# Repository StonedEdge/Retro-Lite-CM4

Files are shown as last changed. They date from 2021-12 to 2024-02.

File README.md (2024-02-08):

Image of Retro Lite CM4
# Retro Lite CM4: Raspberry Pi Handheld

## Description
 
The Retro Lite CM4 is a joint project between Dmcke5 and StonedEdge. The console is powered by a 4000mAh Li-Po and is designed to run with various software images, including but not limited to RetroPie, Lakka or Batocera, directly from an SD card or via eMMC storage. The project housing was inspired by a Nintendo Switch Lite, but is not a 100% match to the original. The CM4 cannot currently emulate most 32/64-bit consoles released after the PSP or Dreamcast. This means GameCube, Wii and 3DS are currently unplayable until the Foundation releases a newer version of the Compute Module line. wiringPi is now a deprecated GPIO library however does work with arm64 and aarch64, so you can install 64-bit RetroPie if you'd like. 

## Features

- Machined aluminum 6061 housing (green/purple), custom machined and anodized by Dmcke5
- Raspberry Pi 4 SoC: Broadcom BCM2711 quad-core Cortex-A72 @ 1.5GHz (ARM CPU overclockable to 2.1GHz, GPU overclockable to 850MHz)
- 2GB of LPDDR4-3200 SDRAM
- 5.0GHz IEEE 802.11b/g/n/ac wireless, Bluetooth 5.0
- Custom AIO 4-layer PCB, with CM4 mezzanines, 5v boost rated at 2.1A continuous current, 3.3v buck, USB2422 hub, BQ24292i, MAX17055 fuel gauge, ATtiny84, WM8960 amp, TFP401 encoder, SD card slot, USB-C hardware and mini HDMI type A
- 2x controller PCBs with FFC cables
- 800 x 480 (5:3 aspect ratio) IPS display
- HDMI video output (HDMI0 - internal)
- 1080p 60fps HDMI video output (HDMI1 - external) via the mini HDMI port
- Tempered glass screen protector
- Fuel gauge for accurate battery SoC monitoring - MAX17055, custom battery indicator shown in steps of 10 icons, plus %SoC value, via dispmanx APIs on a TFT HDMI driven panel
- Charging indicator
- HDMI switching scripts, to shutdown and reboot to external HDMI with an overclock applied
- ATMEGA32u4 internal USB 2.0 HID controller
- Brightness and volume HUD adjustment, in steps of 10 icons. Brightness is adjusted by holding select + up/down on the DPAD
- Custom menu, activated by pushing select + R3. The menu consists of 4 sections (1. Battery Information, 2. Controller Calibration, 3. Onscreen Keyboard, 4. Settings Menu) -   courtesy of Dmcke5's hard work and ideas :D
- USB-C PD charging capabilities up to 15v (0.5C charge rate at 2A) with an original Nintendo Switch charger
- Stereo Audio Output via i2s WM8960 Wolfson audio amplifier
- Headphone jack, with automatic switching
- 4000mAh custom lipo design, providing 4 hours of gameplay
- Dual stacked shoulder buttons (L, R, LZ, RZ)
- 2x switch analog sticks, range programmable in software
- Resin casted ABXY, DPAD, start+select, shoulder buttons with acetal spring hinge + silicone membranes
- Safe software/hardware shutdown to prevent corruption to the SD card data (low voltage shutdown included)
- USB 2.0 2-port downstream hub
- External dock passthrough PCB with 4 port USB-hub - have now started uploading dock assets

Click the link below to view a more detailed buildlog of the Retro Lite CM4: 
https://bitbuilt.net/forums/index.php?threads/retro-lite-cm4-a-stonededge-and-dmcke5-collaboration.3934/

## Requirements to Build the Retro Lite CM4

### Code 

Code has now been split into various header files and the retrolite.c code has now been made easier to read and condensed for the end-user. Code required to complete the handheld includes an ATtiny84 monitor script, which can be flashed via the 1.27mm pitch 6 pin header on the main Retro Lite PCB with an Arduino or similar programmer. Code for the i2s audio amplifier, fuel gauge and OSD functionality can be compiled directly on the CM4 module from the command line. Current code is unfinished as of January 2022, however we are pushing bug fixes when we find them - expect a fully functioning RetroPie image to be shared in the future from this repository (actually, just found out this is not allowed due to the licensing of certain emulators, so will create install scripts at a later date). 

To flash the software to the Retro Lite CM4, you can either download the latest RetroPie Retro Lite custom image, or follow the below steps to get up and running. Plan is to eventually put this into a single script. I have not currently tested our firmware on images other than RetroPie, however I assume other images should also work fine. 

a) Download the latest version of RetroPie for the Raspberry Pi 4/400 here (also compatible with CM4): 
https://retropie.org.uk/download/ 

b) Run the WM8960 I2S audio amplifier script and install audio drivers:
https://github.com/StonedEdge/seeed-voicecard

c) Install the latest version of WiringPi, compatible with both 64/32-bit OS here: 
https://github.com/StonedEdge/WiringPi

d) Add config.txt to the /boot directory (overwrite)

e) cd /home/pi/RetroliteOSD sudo make - compile the Retro Lite CM4 C code and generate binary

f) Navigate to the /etc directory and add the below lines to the rc.local file, to allow the code to run every time at startup 

cd /home/pi/RetroliteOSD
sudo ./retrolite &
sudo ./hdmi_script.sh & 

g) sudo reboot - Reboot to enable all changes 

You should now have all the required software installed for the Retro Lite CM4 to display battery SoC, charging status, WiFi status, bluetooth status and more. The Retro Lite CM4 automatically safely shuts itself down when the voltage of the batteries depletes to 3.1V - adjustable directly from the settings calibration menu. The Retro Lite CM4 must reboot to output video to an external monitor via the mini HDMI type-A port, which is handled by the hdmi_switch.sh script. 

-------------------------------------------------------------------------------------------------------

### CAD
The CAD files for the Retro Lite CM4 are now available and open source! Please do give credit where due as a lot of work has gone into these designs.
You can check out my project partner's work here: https://github.com/dmcke5

-------------------------------------------------------------------------------------------------------

### PCB
The Retro Lite CM4 requires 4 custom designed PCBs to be installed, not including the CM4 carrier board. These include: 

a) Retro Lite CM4 AIO carrier board 

b) Retro Lite Controller PCB (Right)

c) Retro Lite Controller PCB (Left)

d) Retro Lite Button Daughterboard

Gerbers to be ordered from your board house of choice have now been uploaded! Recommended to use JLCPCB for fast turnaround using their 4-layer service.

-------------------------------------------------------------------------------------------------------

### BOM (Bill of Materials) 
Preliminary BOMs for all 4 PCBs have been added including cost. You will have to source your own parts however most can be found on Digikey/Mouser.

-------------------------------------------------------------------------------------------------------
### New Revision Features
Features that I would like to add to the handheld (welcome for others to assist) include the following:

a) HDMI over USB-C, using the TPS65987D and the TUSB546A-DCI high speed mux. 

b) OTG integration (power perihperals through the onboard USB-C port). 

c) DSI 5.5" display (struggle to know of a way to get this working currently on the Pi). 

Feel free to make a pull request with any changes you would like seen to the handheld. 

-------------------------------------------------------------------------------------------------------

### FAQs
Q: How can I get my hands one of these handhelds? Do you sell them? 

A: I am not currently selling kits on this handheld (nor do I plan to for the forseeable future), but I do offer commissions on occassion via my social media. DM me for details. 

Q: Why dont you use a 5.5" display from a Switch Lite? 

A: MIPI reverse engineering is not simple not trivial to a hobbyist like myself. 

Q: Why are your commissions ludicrously priced?

A: Building one off handhelds for people is expensive. Labor & parts dont come cheap either. I'd recommend you build one yourself using the assets from this GitHub or just buy a mass produced emulation handheld from Aliexpress. 

### Optional Docking Station 
Image of Retro Lite CM4

Source code available here:
https://github.com/StonedEdge/Retro-Lite-CM4-Dock

The docking station is now completed! It's designed to work with RetroPie and use a RP2040 microcontroller, written in C (Pico) and Python (CM4). Feel free to build one if you'd like! 

-------------------------------------------------------------------------------------------------------
### Contributors 
I'd like to thank these people in no particular order for the awesome work you have done to help me complete this project. 

* Dmcke5 for designing the case assets, including machining/anodizing the prototypes, doing most of the code and much more. Wouldn't have been possible to complete this without you - a team effort
* YveltalGriffin/Mackie-Kannard Smith, for suggesting various hardware changes and reviews to PCB/schematics + GitHub bugs. His help was invaluable in learning new things about PCB design 
* Juckett D, for creating the Aegis CM4 and offering tips and tricks along the way. Check out his work here and awesome CM4 handheld(s): https://github.com/juckettd
* Aurelio Manarra, for always helping me out with my non EE questions and various other things ᕕ( ᐛ )ᕗ
* Bill, for helping me with the docking station code & bug fixes

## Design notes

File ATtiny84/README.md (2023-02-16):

# ATtiny84 C++ Script

## Description
The purpose of the ATtiny84 onboard micrcontroller is to perform 5 simple functions: 

1) Drive the EN pin of the boost/buck regulators high, to turn on system power 
2) Safely shutdown the operating system via a push button, and shut off regulator output after a reasonable delay (in this case, 10 seconds)
3) Safely shutdown the operating system when battery voltage depletes less than 3.1v to prevent undervoltage/prolong the battery lifespan. This can be set as low as 2.8v but I would not recommend setting it lower than 3.0v to maintain good battery health 
4) Monitor the BQ24292i charging chip over i2c, including setting the correct parameters/registers for the Retro Lite CM4, like max charge current and voltage cutoffs
5) Allow for specific time delays before performing actions (i.e hold button 3 seconds for power off, 1 second power on. 10 second delay before regulators switched off, 30 second low voltage shutdown delay) - adjustable via the powerOn, powerOff, and shutDown variables
6) Set the CM4 to the lowest possible power down state by driving GLOBAL_EN low after software shutdown

### Install Instructions

The easiest way to flash the ATtiny84 is with an Arduino UNO set up as an ICSP (in-circuit serial programmer) directly from within the Arduino IDE.
https://www.arduino.cc/en/software

Please install the below ATtiny cores for Arduino IDE support and choose the internal 8Mhz clock at 5v when programming your ATtiny84. 
https://github.com/damellis/attiny

For further understanding of the BQ24292i, please check the official datasheet below. Magic number code (i.e directly writing hexadecimal values to the write registers) will be eliminated soon, with proper bitshifting logic to be implemented at a later date. 
https://www.ti.com/lit/ds/symlink/bq24292i.pdf

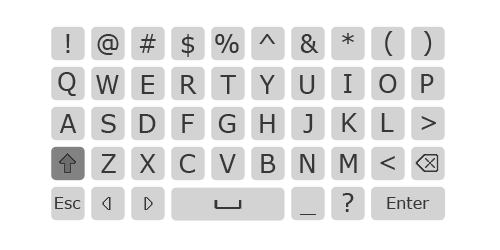
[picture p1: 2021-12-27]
keyboard/upperCase.png

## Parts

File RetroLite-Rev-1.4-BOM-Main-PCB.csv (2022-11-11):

Qty | Available | Value | Device | Package | Board Desginator | Voltage Rating | Power Rating | Description | Additional Notes to PCBA House | Manufacturer Part Number | Unit Price | Total Price | SMT | THT | Original | Remark
1 | YES | N/A | LEDSML0603 | 603 | LEDN_ACT | >3.3V | <1W | Green LED |  | Generic/Cheapest OK | 0.030 | 0.030 | 2 |  | N
1 | YES | N/A | LEDSML0603 | 603 | LEDN_PWR | >3.3V | <1W | Red LED |  | Generic/Cheapest OK | 0.030 | 0.030 | 2 |  | N | New added 20211124
6 | YES | 0 | R-EU_R0402 | 402 | JU_1, JU_2, JU_3, JU_4, JU_5, JU_6 |  | 1/8W or 1/4W | Resistor Jumper |  | Generic/Cheapest OK | 0.000 | 0.000 | 12 |  | N
16 | YES | 0.01uF | CAP_CERAMIC0603_NO | 603 | C2, C3, C5, C6, C7, C8, C9, C10, C11, C21, C22, C25, C49, C51, C53, C54 | >16V | CAP CER SMD 0603 .01UF 10% X7R | Capacitor |  | Generic/Cheapest OK | 0.000 | 0.000 | 32 |  | N
1 | YES | 0.047uF | C-EUC0603 | 603 | C29 | >50V | CAP CER 0.047UF 50V X7R 0603 | Capacitor |  | Generic/Cheapest OK | 0.000 | 0.000 | 2 |  | N
1 | YES | 0.1uF | 0.1UF-0603-25V-(+80/-20%) | 402 | C37 | >10V | CAP CER 1UF 10V X5R 0603 | Capacitor |  | Generic/Cheapest OK | 0.000 | 0.000 | 2 |  | N
1 | YES | 0.1uF | C-EUC0402 | 402 | C65 | >10V | CAP CER 0.1UF 10V X5R 0402 | Capacitor |  | Generic/Cheapest OK | 0.000 | 0.000 | 2 |  | N
7 | ? | 0.1uF | C-EUC0603 | 603 | C12, C13, C17, C18, C19, C26, C62 | >10V | CAP CER 0.1UF 10V X5R 0603 | Capacitor |  | Generic/Cheapest OK | 0.000 | 0.000 | 14 |  | N
1 | ? | 0.1uF | CAP_CERAMIC0603_NO | 603 | C20 | >10V | CAP CER 0.1UF 10V X5R 0603 | Capacitor |  | Generic/Cheapest OK | 0.000 | 0.000 | 2 |  | N
1 | YES | 0.47uF | C-EUC0402 | 402 | C64 | >25V | CAP CER 0.47UF 25V X5R 0402 | Capacitor |  | Generic/Cheapest OK | 0.000 | 0.000 | 2 |  | N
2 | YES | 1-1734839-4 | 1-1734839-4 | TE_1-1734839-4 | LEFTPCB, RIGHTPCB |  |  | Connectors (Controller, Left & Right) |  | Generic/Cheapest OK | 1.081 | 2.162 | 28 |  | Y | Change to original
6 | YES | 1.0uF | 1.0UF-0603-16V-10% | 603 | C41, C42, C43, C44, C47, C68 | >10V | CAP CER 1UF 10V X5R 0603 | Capacitor |  | Generic/Cheapest OK | 0.020 | 0.120 | 12 |  | N
1 | ? | 100k | 100KOHM-0603-1/10W-1% | 402 | R24 |  | 1/10W | Resistor |  | Generic/Cheapest OK | 0.020 | 0.020 | 2 |  | N
1 | YES | 100k | R-EU_R0603 | 603 | R21 |  | 1/8W or 1/4W | Resistor |  | Generic/Cheapest OK | 0.000 | 0.000 | 2 |  | N | 1/10W
1 | YES | 100nF | C-EUC0603 | 603 | C39 | >16V | CAP CER 0.1UF 16V X7R 0603 | Capacitor |  | Generic/Cheapest OK | 0.000 | 0.000 | 2 |  | N
2 | NO | 100uF | C-EUC1206 | 1206 | C35, C36 | >4V | CAP CER 100UF 4V X6S 1206 | Capacitor |  | Generic/Cheapest OK | 0.280 | 0.560 | 4 |  | N
1 | ? | 33k | R-EU_R0603 | 603 | R23 |  | 1/10W | Resistor |  | Generic/Cheapest OK | 0.000 | 0.000 | 2 |  | N
5 | YES | 10 | R-EU_R0603 | 603 | R15, R16, R17, R18, R19 |  | 1/8W or 1/4W | Resistor |  | Generic/Cheapest OK | 0.000 | 0.000 | 10 |  | N | 1/10W
2 | YES | 10k | R-EU_R0402 | 402 | R43, R49 |  | 1/8W or 1/4W | Resistor |  | Generic/Cheapest OK | 0.000 | 0.000 | 4 |  | N | 1/16W
9 | YES | 10k | R-EU_R0603 | 603 | R10, R31, R34, R36, R37, R42, R44, R52, R56 |  | 1/8W or 1/4W | Resistor |  | Generic/Cheapest OK | 0.000 | 0.000 | 18 |  | N | 1/10W
2 | YES | 10k | R-EU_R0603 | 603 | R45, R46 |  | 1/8W or 1/4W | Resistor |  | Generic/Cheapest OK | 0.000 | 0.000 | 4 |  | N | 1/10W
2 | YES | 10uF | 1.0UF-0805-25V-(+80/-20%) | 805 | C46, C59 | >6.3V | CAP CER 10UF 6.3V X5R 0805 | Capacitor |  | Generic/Cheapest OK | 0.020 | 0.040 | 4 |  | N
2 | YES | 10uF | C-EUC0805 | 805 | C66, C67 | >6.3V | CAP CER 10UF 6.3V X5R 0805 | Capacitor |  | Generic/Cheapest OK | 0.020 | 0.040 | 4 |  | N
5 | YES | 10uF | C-EUC0805 | 805 | C4, C23, C27, C28, C31 | >6.3V | CAP CER 10UF 6.3V X5R 0805 | Capacitor |  | Generic/Cheapest OK | 0.020 | 0.100 | 10 |  | N
1 | YES | 1140084168 | 1140084168 | AMPHENOL_1140084168 | M-SD |  | CAP CER 10UF 6.3V X5R 0805 | Connector |  | Generic/Cheapest OK | 0.950 | 0.950 | 14 |  | N
1 | ? | 12k | 12KOHM-0603-1/10W-1% | 603 | R25 |  | 1/10W | Resistor |  | Generic/Cheapest OK | 0.000 | 0.000 | 2 |  | N
1 | YES | 12k | R-EU_R0603 | 603 | R2 |  | 1/8W or 1/4W | Resistor |  | Generic/Cheapest OK | 0.000 | 0.000 | 2 |  | N | 1/10W
1 | YES | 15k | R-EU_R0603 | 603 | R55 |  | 1/8W or 1/4W | Resistor |  | Generic/Cheapest OK | 0.000 | 0.000 | 2 |  | N | 1/10W
1 | YES | 162k | R-US_R0603 | 603 | R35 |  | 1/8W or 1/4W | Resistor |  | Generic/Cheapest OK | 0.000 | 0.000 | 2 |  | N | 1/10W
1 | YES | 18nF | CAP_CERAMIC0603_NO | 603 | C61 | >10V | CAP CER 0.018UF 25V X7R 0603 | Capacitor |  | Generic/Cheapest OK | 0.000 | 0.000 | 2 |  | N
2 | YES | 18pF | C-EUC0603 | 603 | C45, C48 | >10V | CAP CER 18PF 25V 0603 | Capacitor |  | Generic/Cheapest OK | 0.000 | 0.000 | 4 |  | N
1 | ? | 1k | R-US_R0603 | 603 | R30 |  | 1/10W | Resistor |  | Generic/Cheapest OK | 0.000 | 0.000 | 2 |  | N
2 | YES | 1k | R-EU_R0603 | 603 | R13, R54 |  | 1/8W or 1/4W | Resistor |  | Generic/Cheapest OK | 0.000 | 0.000 | 4 |  | N | 1/10W
4 | YES | 1uF | C-EUC0603 | 603 | C30, C38, C40, C55 | >10V | CAP CER 1UF 10V X5R 0603 | Capacitor |  | Generic/Cheapest OK | 0.012 | 0.048 | 8 |  | N
2 | YES | 1uF | C-EUC0805 | 805 | C33, C34 | >25V | CAP CER 1UF 25V X7R 0805 | Capacitor |  | Generic/Cheapest OK | 0.015 | 0.030 | 4 |  | N
3 | YES | 1uF | CAP_CERAMIC0603_NO | 603 | C32, C60, C63 | >10V | CAP CER 1UF 10V X5R 0603 | Capacitor |  | Generic/Cheapest OK | 0.012 | 0.036 | 6 |  | N
2 | YES | 1uF | C-EUC0603 | 603 | C56, C69 | >10V | CAP CER 1UF 10V X5R 0603 | Capacitor |  | Generic/Cheapest OK | 0.012 | 0.024 | 4 |  | N
1 | YES | 1uF | C-EUC0805 | 805 | C1 | >25V | CAP CER 1UF 25V X7R 0805 | Capacitor |  | Generic/Cheapest OK | 0.015 | 0.015 | 2 |  | N
1 | ? | 2.2k | R-EU_R0603 | 603 | R48 |  | 1/10W | Resistor |  | Generic/Cheapest OK | 0.000 | 0.000 | 2 |  | N
1 | YES | 2026560021 | 2026560021 | CONN_2026560021_MOL | J3 |  |  | Fan Connector |  | 2026560021 | 0.620 | 0.620 | 4 |  | Y
1 | YES | 220nF | C-EUC0603 | 603 | C57 | >10V | CAP CER 0603 220NF 16V X7R 10% | Capacitor |  | Generic/Cheapest OK | 0.000 | 0.000 | 2 |  | N
3 | YES | 22uF | CAP_CERAMIC0603_NO | 603 | C24, C50, C52 | >6.3V | CAP CER 22UF 6.3V X5R 0603 | Capacitor |  | Generic/Cheapest OK | 0.100 | 0.300 | 6 |  | N
1 | YES | 22uH | VLCF4020T-220MR56 | VLCF4020_1 | L8 |  | CAP CER 22UF 6.3V X5R 0603 | TDK VLCF4020 Series Shielded Wire-wound SMD Inductor 22 uH +/-20% 800mA |  | VLCF4020T-220MR56 | 0.960 | 0.960 | 2 |  | Y
1 | NO | 24LC02BT-I/OT | EEPROM_I2C_MCP24AA32 | SOT23-5 | U2 |  |  | Microchip 32K (4K x 8) 1.8V I2C EEPROM | https://www.digikey.com/en/products/detail/microchip-technology/24LC02BT-I-LT/2039839 This should work as an alternative… | 24LC02BT-I/OT |  |  |  |  |  | change to DNI 20220528
1 | YES | 261 | R-EU_R0603 | 603 | R41 |  | 1/8W or 1/4W | Resistor |  | Generic/Cheapest OK | 0.000 | 0.000 | 2 |  | N | 1/10W
7 | YES | 33 | CAT16-330J4LFCT-ND | CAT16-330J4LFCT-ND | R1, R6, R7, R8, R9, R12, R14 |  | 1/8W or 1/4W | Resistor | RES ARRAY 4 RES 33 OHM 1206 | Generic/Cheapest OK | 0.020 | 0.140 | 56 |  | N | 1/10W
6 | YES | 4.7k | R-EU_R0603 | 603 | R5, R32, R33, R38, R47, R53 |  | 1/8W or 1/4W | Resistor |  | Generic/Cheapest OK | 0.000 | 0.000 | 12 |  | N | 1/10W
2 | YES | 4.7k | RESISTOR_0603_NOOUT | 603 | R3, R4 |  | 1/8W or 1/4W | Resistor |  | Generic/Cheapest OK | 0.000 | 0.000 | 4 |  | N | 1/10W
3 | YES | 4.7uF | C-EUC0603 | 603 | C14, C15, C16 | >10V | CAP CER 4.7UF 10V X5R 0603 | Capacitor |  | Generic/Cheapest OK | 0.050 | 0.150 | 6 |  | N
1 | ? | 4.7uF 50v | C-EUC0603 | 805 | C58 | >10V | CAP CER 4.7UF 10V X5R 0603 | Capacitor |  | Generic/Cheapest OK | 0.050 | 0.050 | 2 |  | N | 10V
2 | YES | 5.1k | R-EU_R0603 | 603 | R11, R20 |  | 1/8W or 1/4W | Resistor |  | Generic/Cheapest OK | 0.000 | 0.000 | 4 |  | N | 1/10W
1 | YES | 510k | R-US_R0603 | 603 | R26 |  | 1/8W or 1/4W | Resistor |  | Generic/Cheapest OK | 0.000 | 0.000 | 2 |  | N | 1/10W
4 | YES | 56k | 100KOHM-0603-1/10W-1% | 603 | R27, R28, R29, R40 |  | 1/8W or 1/4W | Resistor |  | Generic/Cheapest OK | 0.000 | 0.000 | 8 |  | N | 1/10W
1 | NO | 5 | R-EU_R0603 | 603 | R22 |  | 1/8W or 1/4W | Resistor | Ensure tolerance <0.1%. TPS61160A boost converter sense resistor for backlight. Range can be between 4.9 ohms and 5.5 ohms. Please find what is available. | Generic/Cheapest OK | 0.890 | 0.890 | 2 |  | Y | Price based on CPF0603B5R1E1
1 | YES | 685119136923 | 685119136923 | WURTH_685119136923 | J5 |  |  | Mini HDMI Connector |  | 685119136923 | 3.941 | 3.941 | 19 | 4 | Y
1 | YES | 78171-0005 | 78171-0005 | MOLEX_78171-0005 | J4 |  |  | Pico EZ Mate Battery Connector |  | 781710005 | 0.625 | 0.625 | 5 |  | Y
4 | YES | DMN3730-U7 | DMN3730-U7 | SOT95P280X125-3N | Q1, Q2, Q3, Q4 |  |  | Mosfets |  | DMN3730U-7 | 0.300 | 1.200 | 12 |  | Y
1 | YES | ASPI-0630HI | ASPI-0630HI | ASPI-0630HI | L6 |  |  | Inductor |  | ASPI-0630HI-2R2M-T15 | 1.128 | 1.128 | 2 |  | Y
1 | YES | BAS70 | BAS70 | SOT23 | D1 |  |  | Schottky Diode | SCHOTTKY SOT-23 70V 0.07A | Generic/Cheapest OK | 0.050 | 0.050 | 3 |  | Y
1 | YES | BQ24292I | BQ24292I | QFN50P400X400X100-25N | U5 |  |  | Battery IC |  | BQ24292IRGET | 7.741 | 7.741 | 24 |  | Y
1 | YES | BUF-74LVC1G07 | BUF-74LVC1G07 | BUF-74LVC1G07 | U22 |  |  | IC Buffer |  | SN74LVC1G07DCKR | 1.200 | 1.200 | 5 |  | Y | change to SN74LVC1G07DCKR 20211124
2 | YES | DF40C-100DS-0.4V(51) | DF40C-100DS-0.4V(51) | HRS_DF40C-100DS-0.4V(51) | 1-100, 101-200 |  |  | B2B Mezannines |  | DF40C-100DS-0.4V(51) | 1.500 | 3.000 | 200 |  | N
1 | YES | ECS-240-8-36CKM-TR | ECS-240-8-36CKM-TR | XTAL_ECS-160-10-36-JGN-TR | Y2 |  |  | SMD Crystal |  | ECS-240-8-36CKM-TR | 1.778 | 1.778 | 4 |  | Y | Change to ECS-3225MV-240-BN-TR
1 | YES | ECS-3225MV-240-BN-TR | ECS-3225MV-240-BN-TR | OSC_ECS-2333-160-BN-TR | Y1 |  |  | SMD Crystal |  | ECS-3225MV-240-BN-TR | 1.750 | 1.750 | 4 |  | Y
1 | YES | ESDA25P35-1U1M | ESDA25P35-1U1M | ESDA8P801U1M | D3 |  |  | Diode |  | ESDA25P35-1U1M | 0.500 | 0.500 | 2 |  | Y
1 | YES | ESDA25W | ESDA25W | SOT65P210X110-3N | D2 |  |  | Diode |  | ESDA25W | 0.650 | 0.650 | 3 |  | Y
4 | YES | Ferrite | MMZ2012R601AT000 | FERRITE BEAD 600 OHM 0805 1LN | FB1, FB2, FB3, FB4 |  |  | Ferrite Beaed | FERRITE BEAD 600 OHM 0805 1LN | Generic/Cheapest OK | 0.030 | 0.120 | 8 |  | N | added FB2, FB3, FB4 20211124
1 | YES | RT9742 | RT9742 | RT9742 | MICROSD_SWI |  |  | Power Switch MicroSD Card |  | RT9742CNGJ5 | 2.042 | 2.042 | 5 |  | Y
1 | YES | MDWK4040T1R0MMV | MDWK4040T1R0MMV | MDWK4040T1R0MMV | U18 |  |  | Inductor |  | MDWK4040T1R0MMV | 1.320 | 1.320 | 2 |  | Y
1 | YES | IP2721 | IP2721 | TSSOP-16 | U7 |  |  | USB-C PD Sink | Purchase if available (not available from Digikey/Mouser) | IP2721 | 1.215 | 1.215 | 16 |  | Y
1 | YES | MAX17055ETB+T | MAX17055ETB+T | 21-100013A_T102A2+1C_MXM | U11 |  |  | Fuel Gauge |  | MAX17055ETB+T | 6.837 | 6.837 | 10 |  | Y
1 | YES | MBR0540T1G | MBR0540T1G | SOD3716X135N | D4 |  |  | Schottky Diode |  | MBR0540T1G | 0.400 | 0.400 | 2 |  | Y
1 | YES | MCU-ATTINY84A-MU(QFN20) | MCU-ATTINY84A-MU(QFN20) | QFN20G-0.5-4X4MM | U14 |  |  | ATTiny |  | ATTINY84A-MUR |  |  |  |  |  | Out of stcok
1 | YES | PS0306DRF7T0R01L | PS0306DRF7T0R01L | PS0306DRF7T0R01L | R39 |  | >= 0.5W | Sense Resistor | Ensure tolerance <0.5%, 1/2W minimum. See part number. Must be 0.01 ohm. | PS0306DRF7T0R01L | 0.703 | 0.703 | 2 |  | Y
3 | YES | RCLAMP0582BQTCT | RCLAMP0582BQTCT | SC75-3L_SEM | U10, U12, U13 |  |  | Clamp Diode |  | RCLAMP0582BQTCT | 1.517 | 4.551 | 9 |  | Y
1 | YES | S62684-402100ALF | S62684-402100ALF | S62684-402100ALF | U3 |  |  | 40 Pin FFC |  | 62684-402100AHLF | 0.300 | 0.300 | 40 |  | N
1 | YES | SJ-43516-SMT | SJ-43516-SMT | CUI_SJ-43516-SMT | J2 |  |  | Headphone Jack |  | SJ-43516-SMT-TR | 0.500 | 0.500 | 4 |  | N
2 | YES | SN74LVC1G17DCKR | SN74LVC1G17DCKR | SOT65P210X110-5N | U19, U20 |  |  | IC Buffer |  | SN74LVC1G17DCKR | 0.400 | 0.800 | 10 |  | Y
1 | YES | TFP401 | TFP401 | S-PQFP-G100 | U1 |  |  | TFP401 PanelBus Digital Receiver |  | TFP401AMPZPEP | 27.923 | 27.923 | 55 |  | Y
1 | YES | TPS22948 | TPS22948 | SOT65P210X110-6N | U15 |  |  | IC Power Management |  | TPS22948DCKR |  |  |  |  |  | Out of stcok
1 | YES | TPS61160ADRVT | TPS61160ADRVT | SON65P200X200X80-7N | U17 |  |  | White LED Driver with PWM Brightness Control in 2mm x 2mm Package. Up to 10 LEDs in Series |  | TPS61160ADRVT | 3.055 | 3.055 | 6 |  | Y
1 | YES | TPS61230DRCT | TPS61230DRCT | SON50P300X300X100-11N | U8 |  |  | Voltage Regulators - Switching Regulators HE Sync Boost Converter |  | TPS61230DRCT |  |  |  |  |  | change to TPS61232, out of stock
1 | YES | TPS82085 | TPS82085 | SON65P280X300X133-9N | U16 |  |  | IC Buck Regulator |  | TPS82085SILT |  |  |  |  |  | Out of stcok
1 | YES | TS3USB221A | TS3USB221A | QFN-10-RSE | U4 |  |  | DPDT Analog Muxer |  | TS3USB221ARSER | 2.615 | 2.615 | 10 |  | Y
1 | YES | U262-161N-4BVC11 | U262-161N-4BVC11 | U262-161N-4BVC11 | J1 |  |  | USB-C Connector |  | U262-161N-4BVC11 | 0.350 | 0.350 | 16 | 4 | Y
1 | YES | USB2422T/MJ | USB2422T/MJ | SQFN24_4X4MC_MCH | U9 |  |  | USB Hub |  | USB2422/MJ |  |  |  |  |  | Out of stcok
1 | YES | WM8960 | WM8960 | QFN50P500X500X100-33N | U6 |  |  | I2S Audio Amplifier |  | WM8960CGEFL/V | 7.126 | 7.126 | 32 |  | Y
1 | YES | MOLEX_0781710004 | 781710004 | 781710004 | J7 |  |  | Connector |  | 781710004 | 0.566 | 0.566 | 6 |  | Y
 |  |  |  |  |  |  |  |  |  |  | Total | 91.301 | 866 | 8

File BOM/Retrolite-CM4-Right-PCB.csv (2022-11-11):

Qty | Value | Device | Package | Parts | Description | Unit Price | Total Price | SMT | THT | Original | Remark
4 | 0.1uF | WCAP-CSGP_0805_885012006018_WAVE | WCAP-CSGP_0805_WAVE | C3, C5, C9, C10 | WCAP-CSGP Ceramic Capacitors | 0.000 | 0.000 | 8 |  | N
2 | 22 | 22OHM-0805-1/4W-1% | 805 | R4, R5 | 22Ω resistor | 0.000 | 0.000 | 4 |  | N
1 | 545500571 | 545500571 | 545500571 | JOYSTICK | Joystick FFC Connector | 1.354 | 1.354 | 7 |  | Y
1 | 1-1734839-4 | 1-1734839-4 | TE_1-1734839-4 | J2 | Conn FPC Connector SKT 14 POS 0.5mm Solder RA SMD T/R | 1.081 | 1.081 | 14 |  | Y
3 | 1.0uF | WCAP-CSGP_0805_885012006018_WAVE | WCAP-CSGP_0805_WAVE | C6, C7, C8 | WCAP-CSGP Ceramic Capacitors | 0.020 | 0.060 | 6 |  | N
3 | 10k | 10KOHM-0603-1/10W-1% | 603 | R1, R6, R7 | 10kΩ resistor | 0.000 | 0.000 | 6 |  | N
1 | 10uF | WCAP-CSGP_0805_885012006018_WAVE | WCAP-CSGP_0805_WAVE | C4 | WCAP-CSGP Ceramic Capacitors | 0.020 | 0.020 | 2 |  | N
1 | 16MHz | CRYSTAL-16MHZSMD-5X3.2 | CRYSTAL-SMD-5X3.2-4PAD | Y1 | 16MHz Crystal | 0.500 | 0.500 | 4 |  | N | 5TJ416000NYGBC
2 | 22pF | 22PF-0603-50V-5% | 603 | C1, C2 | 22pF ceramic capacitors | 0.000 | 0.000 | 4 |  | N
2 | 330 | 300OHM-0603-1/10W-1% | 603 | R2, R3 | 1.6kΩ resistor | 0.000 | 0.000 | 4 |  | N
1 | A | EVQ-Q2B03W | EVQQ2_3 | A | Tact Switch | 0.330 | 0.330 | 4 |  | N
1 | ATMEGA32U4-AU | ATMEGA32U4-AU | QFP80P1200X1200X120-44N | ATMEGA32U4-AU | 8-bit Microcontroller with ISP Flash and USB Controller Check prices | 25.904 | 25.904 | 44 |  | Y
1 | B | EVQ-Q2B03W | EVQQ2_3 | B | Tact Switch | 0.330 | 0.330 | 4 |  | N
1 | GREEN | LED-GREEN0603 | LED-0603 | D1 | Green SMD LED | 0.030 | 0.030 | 2 |  | N
1 | SKRTLAE010 | SKRTLAE010 | SW3_SKRTLAE010_ALPS | RT1 | Shoulder Button | 0.500 | 0.500 | 5 |  | N
1 | START | EVQ-Q2B03W | EVQQ2_3 | START | Tact Switch | 0.330 | 0.330 | 4 |  | N
1 | T2 | EVQ-Q2B03W | EVQQ2_3 | RT2 | Tact Switch | 0.330 | 0.330 | 4 |  | N
1 | X | EVQ-Q2B03W | EVQQ2_3 | X | Tact Switch | 0.330 | 0.330 | 4 |  | N
1 | Y | EVQ-Q2B03W | EVQQ2_3 | Y | Tact Switch | 0.330 | 0.330 | 4 |  | N
1 | Yellow | LED-YELLOW0603 | LED-0603 | D2 | Yellow SMD LED 0603 | 0.030 | 0.030 | 2 |  | N
 |  |  |  |  |  | Total | 31.459 | 136 | 0
 |  |  |  |  |  | s

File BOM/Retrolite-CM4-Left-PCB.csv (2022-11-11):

Qty | Value | Device | Package | Parts | Description | Unit Price | Total Price | SMT | THT | Original | Remark | VALUE
2 | 0.1uF | 0.1UF-0603-25V-5% | 603 | C1, C2 | 0.1µF ceramic capacitors | 0.000 | 0.000 | 4 |  | N |  | 0.1uF
1 | 545500571 | 545500571 | 545500571 | JOYSTICK | Joystick FFC conector | 1.354 | 1.354 | 7 |  | Y
1 | 1-1734839-4 | 1-1734839-4 | TE_1-1734839-4 | J1 | Conn FPC Connector SKT 14 POS 0.5mm Solder RA SMD T/R | 1.081 | 1.081 | 14 |  | Y
6 | EVQ-Q2B03W | EVQ-Q2B03W | EVQQ2_3 | DPAD_DN, DPAD_L, DPAD_R, DPAD_UP, L2, SELECT | Trigger Button | 0.330 | 1.980 | 24 |  | N
1 | SKRTLAE010 | SKRTLAE010 | SW3_SKRTLAE010_ALPS | L1 |  | 0.500 | 0.500 | 5 |  | N
 |  |  |  |  |  | Total | 4.915 | 54 | 0

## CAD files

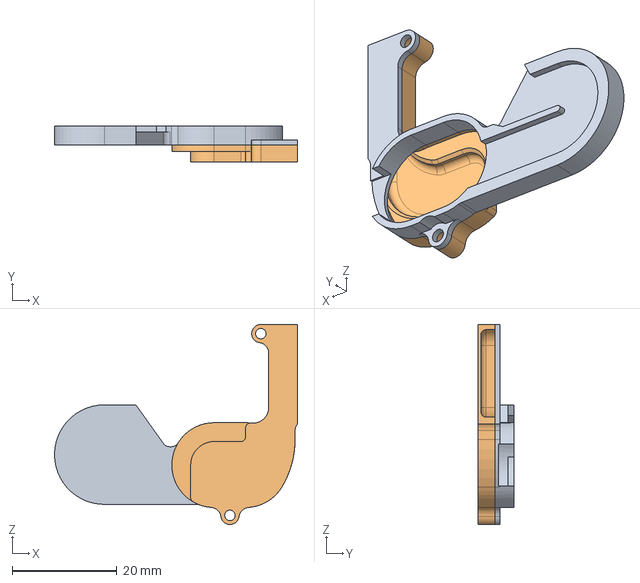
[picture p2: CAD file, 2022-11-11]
CAD Files/Housing/MirrorSpeaker Assembly.step
46.4 x 6.80 x 38.2 mm
MirrorSpeaker Duct
MirrorSpeaker Duct Lower

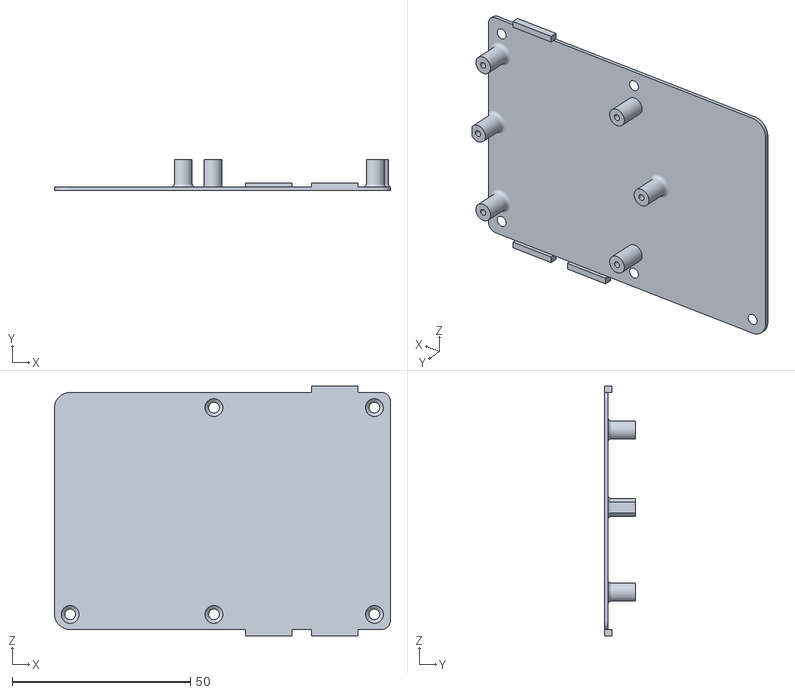
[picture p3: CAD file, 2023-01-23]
CAD Files/Dock/Dock Lid.stl
94.2 x 8.74 x 70.0

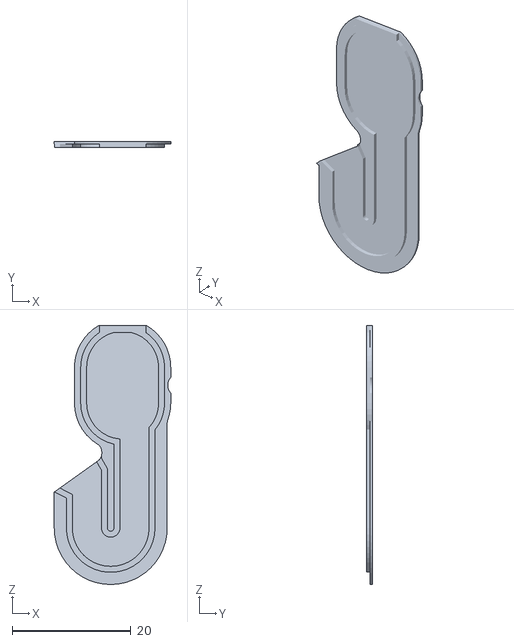
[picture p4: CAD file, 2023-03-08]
CAD Files/Housing/Printed-Speaker-Duct-Lid-Mirrored.stl
19.6 x 1.00 x 43.5

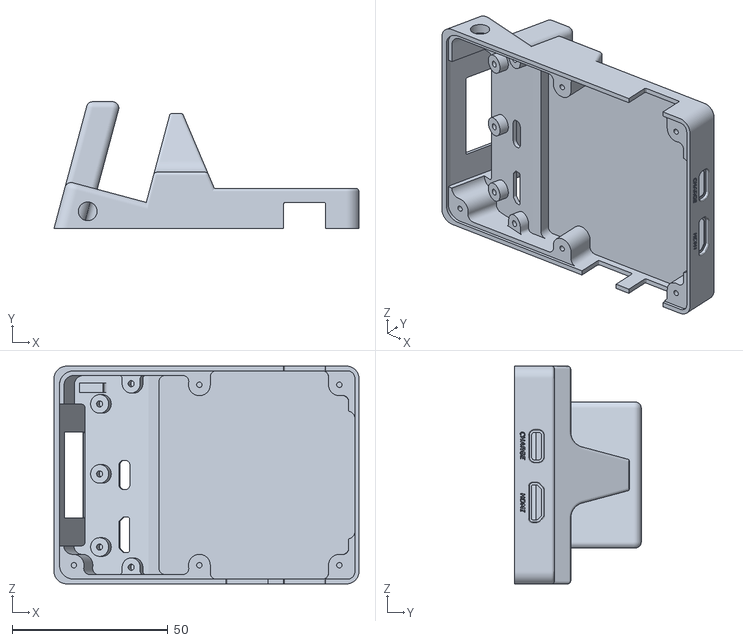
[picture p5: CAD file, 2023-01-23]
CAD Files/Dock/Dock Body.stl
98.0 x 40.7 x 70.0

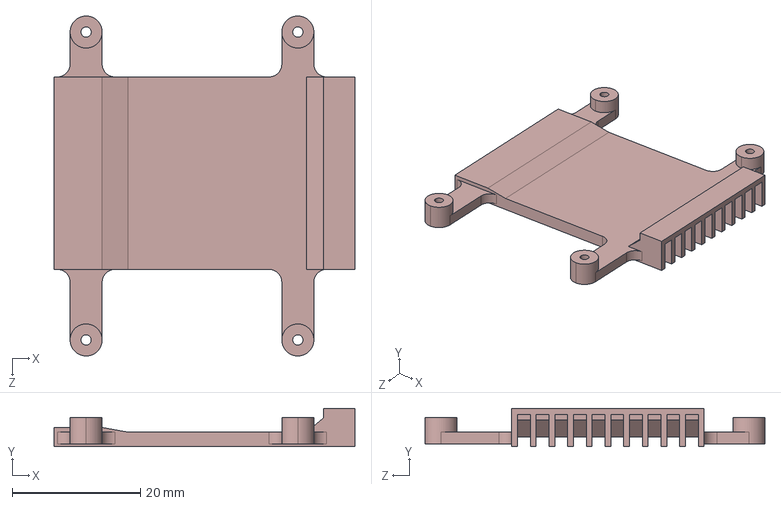
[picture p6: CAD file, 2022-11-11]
CAD Files/Housing/Heatsink-V2.step
46.9 x 6.00 x 53.0 mm

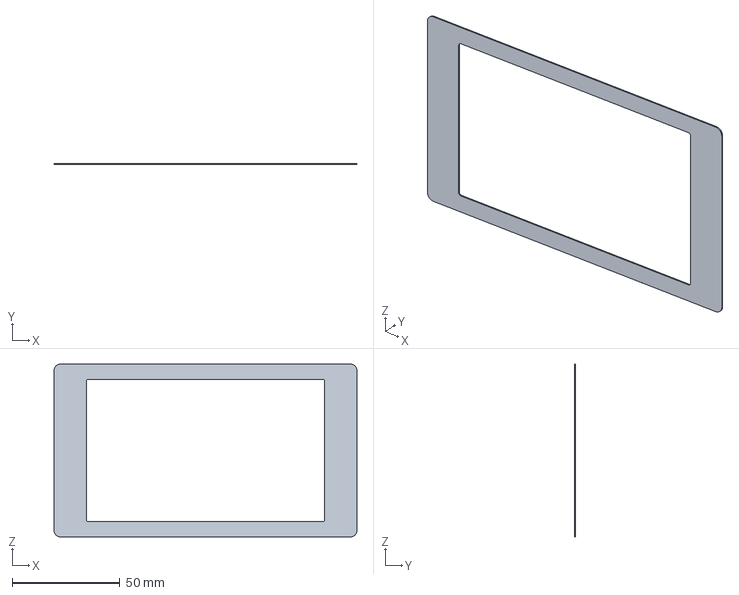
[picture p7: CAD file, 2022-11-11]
CAD Files/Housing/Screen Protector.step
140.8 x 0.5 x 80.3 mm

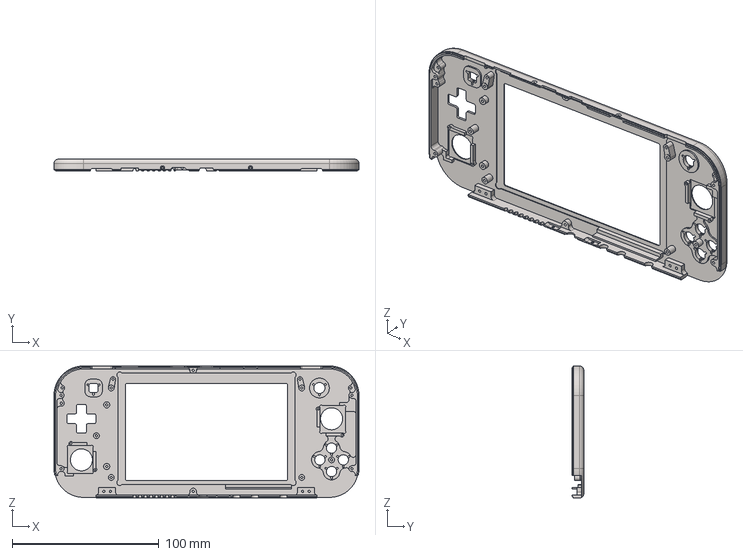
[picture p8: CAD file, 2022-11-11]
CAD Files/Housing/Retro Lite CM4 Front v1.step
208.0 x 8.00 x 90.0 mm

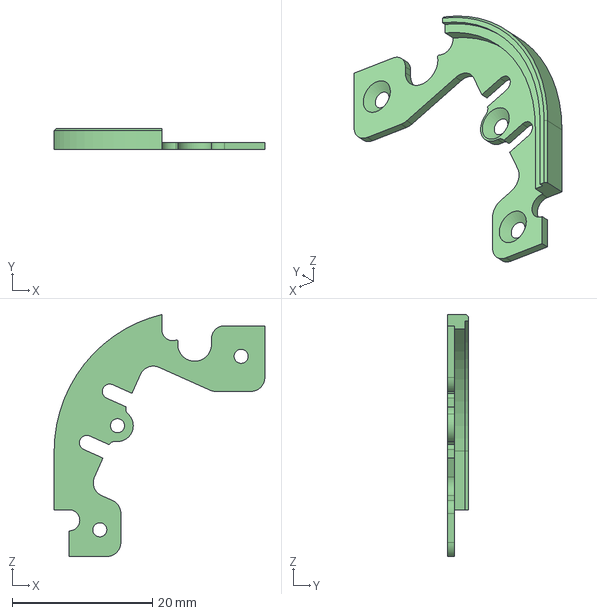
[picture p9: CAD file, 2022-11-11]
CAD Files/Housing/Trigger Mounts Left.step
30.0 x 3.00 x 34.5 mm
Trigger Mount
MirrorTrigger Mount

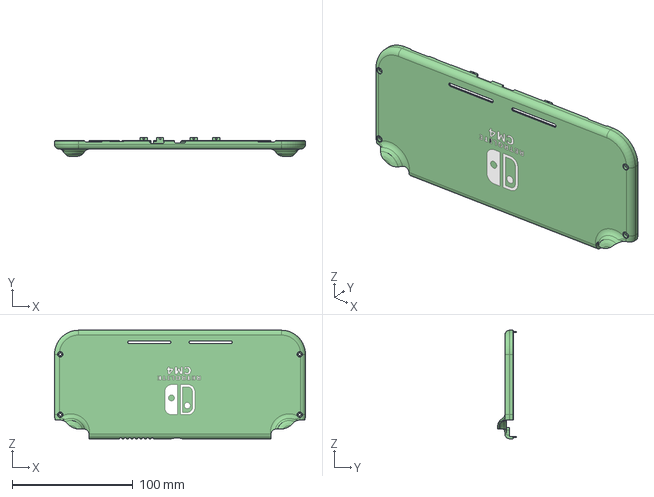
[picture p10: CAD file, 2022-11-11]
CAD Files/Housing/Retro Lite CM4 Rear v1.step
208.0 x 15.5 x 90.0 mm

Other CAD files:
CAD Files/Housing/Speaker Assembly.step
CAD Files/Housing/Printed-Speaker-Duct-Lid.stl
CAD Files/Housing/Trigger Mounts Right.step

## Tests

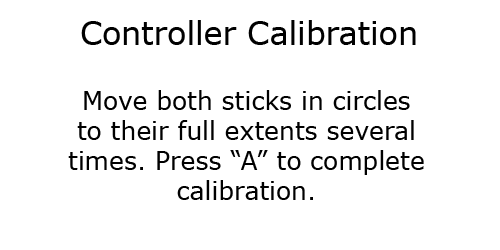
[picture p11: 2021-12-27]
overlays/calibration2.png

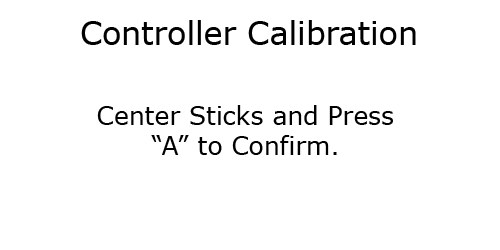
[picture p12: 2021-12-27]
overlays/calibration1.png

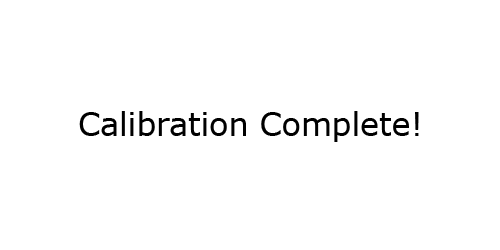
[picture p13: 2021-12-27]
overlays/calibration3.png

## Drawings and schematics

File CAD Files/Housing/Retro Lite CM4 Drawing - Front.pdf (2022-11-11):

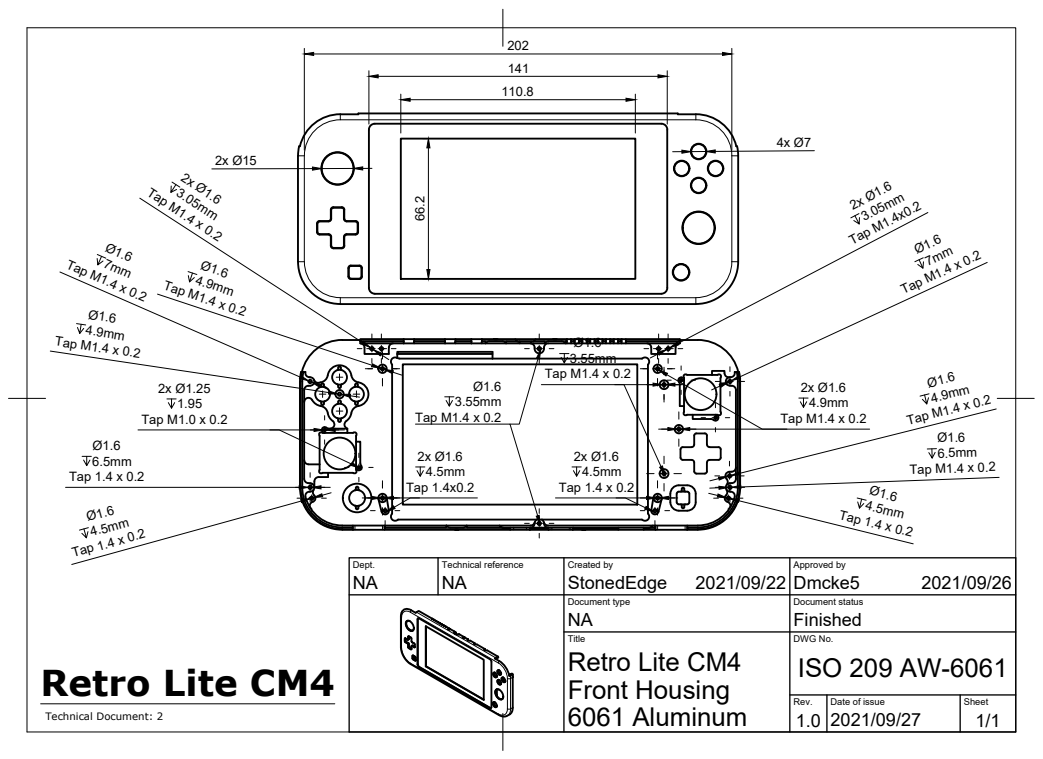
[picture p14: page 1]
2x Ø1.6 Tap M1.4 x 0.2 3.05mm 2x Ø1.6 3.05mm Tap M1.4x0.2; Tap 1.4 x 0.2; Ø1.6 Tap M1.4 x 0.2 7mm; Tap M1.4 x 0.2; Tap 1.4x0.2; Retro Lite CM4; Technical Document: 2; Ø1.6 7mm Tap M1.4 x 0.2; Ø1.6 4.9mm Tap M1.4 x 0.2; Tap M1.0 x 0.2; 4.5mm Ø1.6 Tap 1.4 x 0.2 4.5mm Tap 1.4 x 0.2; 4.9mm Tap M1.4 x 0.2

Dept. NA | Technical reference NA | Created by StonedEdge 2021/09/22 | Approved by Dmcke5 2021/09/26

Document type NA | Document status Finished

Title Retro Lite CM4 Front Housing 6061 Aluminum | DWG No. ISO 209 AW-6061

Rev. 1.0 | Date of issue 2021/09/27 | Sheet 1/1

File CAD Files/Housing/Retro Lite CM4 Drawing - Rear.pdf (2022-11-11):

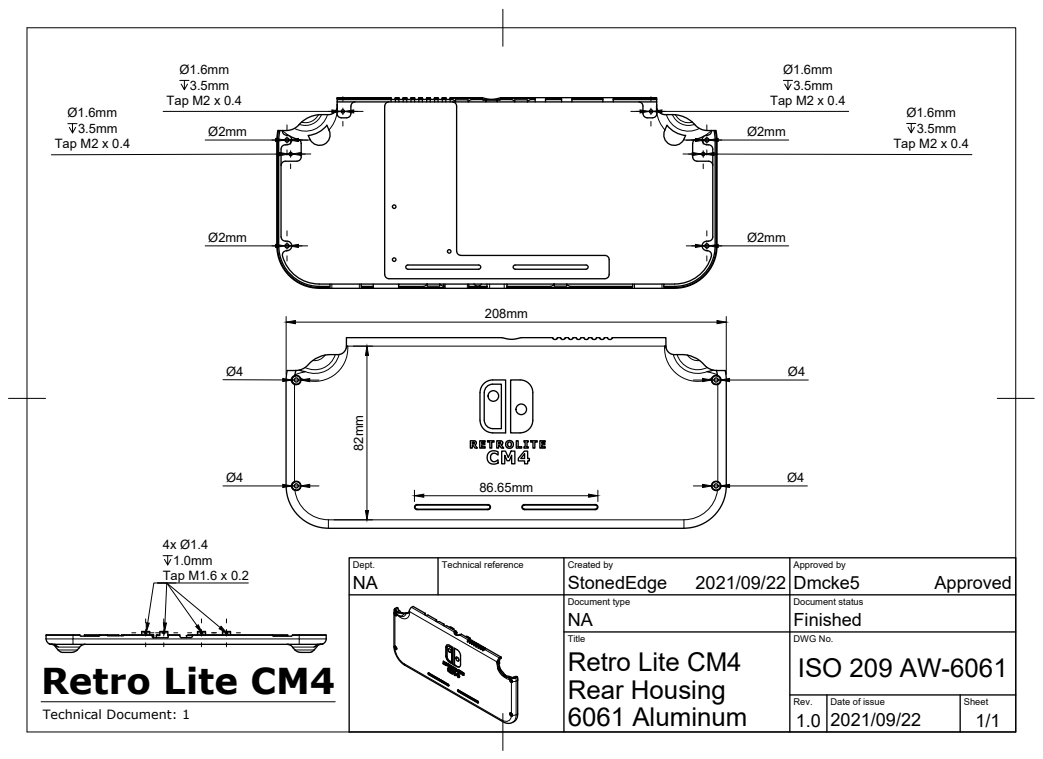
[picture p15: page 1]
Tap M2 x 0.4; Tap M2 x 0.4 Ø1.6mm; Retro Lite CM4 82mm; Tap M1.6 x 0.2; Technical Document: 1

Dept. NA | Technical reference | Created by StonedEdge 2021/09/22 | Approved by Dmcke5 Approved

Document type NA | Document status Finished

Title Retro Lite CM4 Rear Housing 6061 Aluminum | DWG No. ISO 209 AW-6061

Rev. 1.0 | Date of issue 2021/09/22 | Sheet 1/1

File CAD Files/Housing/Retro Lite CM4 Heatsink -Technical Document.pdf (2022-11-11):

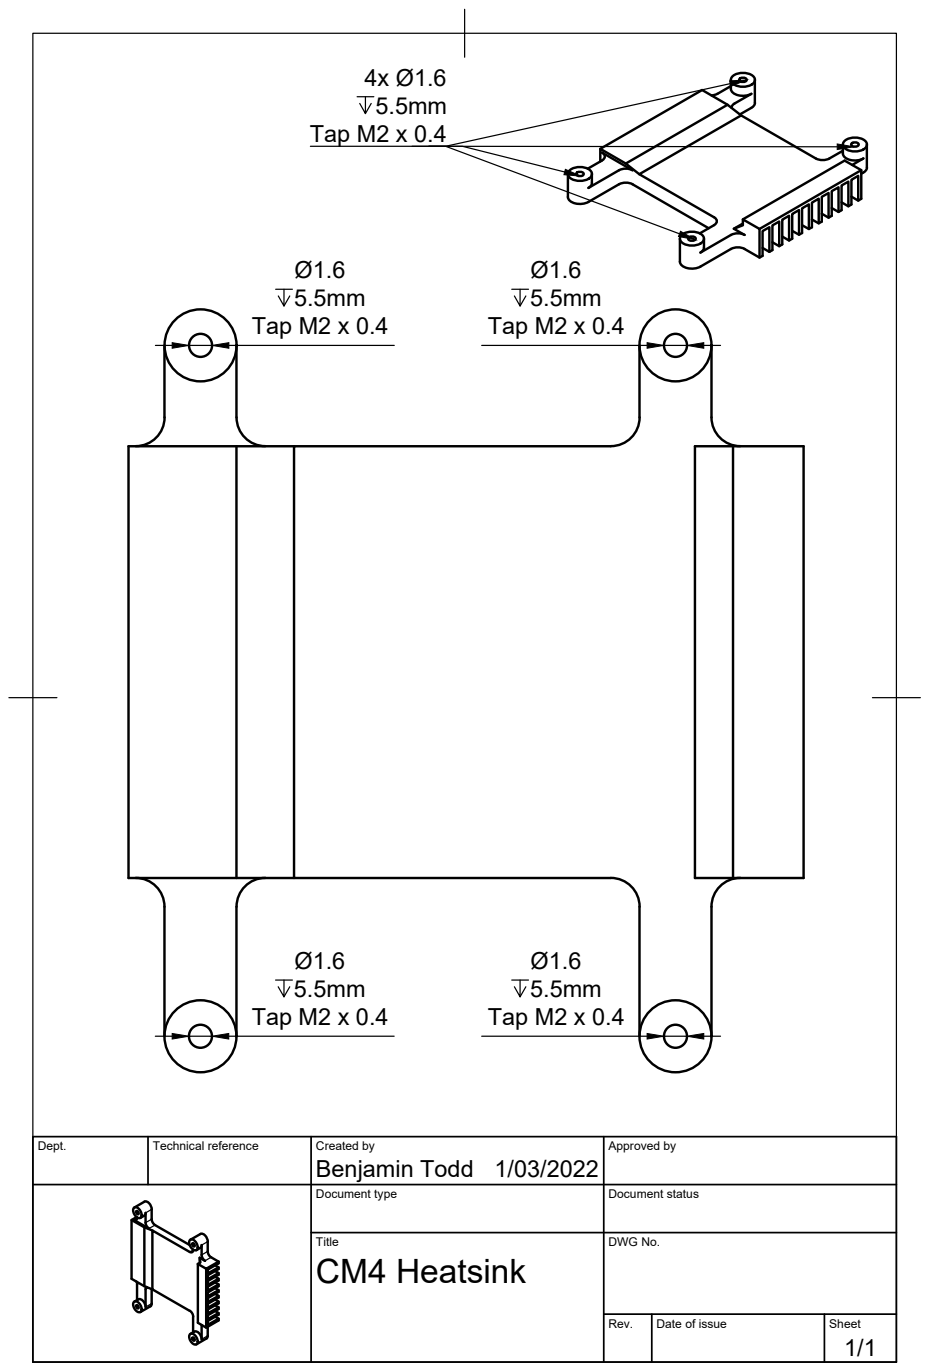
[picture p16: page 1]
Tap M2 x 0.4

Dept. | Technical reference | Created by Benjamin Todd 1/03/2022 | Approved by

Document type | Document status

Title CM4 Heatsink | DWG No.

Rev. | Date of issue | Sheet 1/1

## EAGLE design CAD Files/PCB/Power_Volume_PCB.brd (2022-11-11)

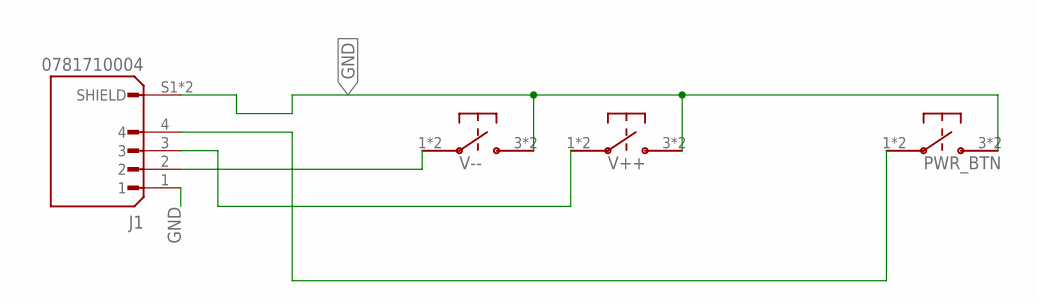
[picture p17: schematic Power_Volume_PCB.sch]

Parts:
J1: 0781710004; MOLEX_0781710004
PWR_BTN: TL3315NF100Q
V++: TL3315NF100Q
V--: TL3315NF100Q

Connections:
GND: J1.1, J1.S1 (SHIELD), J1.S2 (SHIELD), PWR_BTN.3, PWR_BTN.4, V++.3, V++.4, V--.3, V--.4
unnamed: J1.4, PWR_BTN.1, PWR_BTN.2
unnamed: J1.3, V++.1, V++.2
unnamed: J1.2, V--.1, V--.2

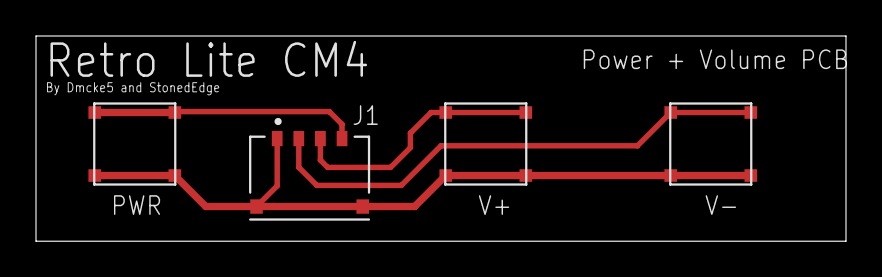
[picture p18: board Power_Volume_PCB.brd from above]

Board: 2 copper layers, 45.0 x 11.4 mm, 4 parts (0 on the bottom side), 4 nets.

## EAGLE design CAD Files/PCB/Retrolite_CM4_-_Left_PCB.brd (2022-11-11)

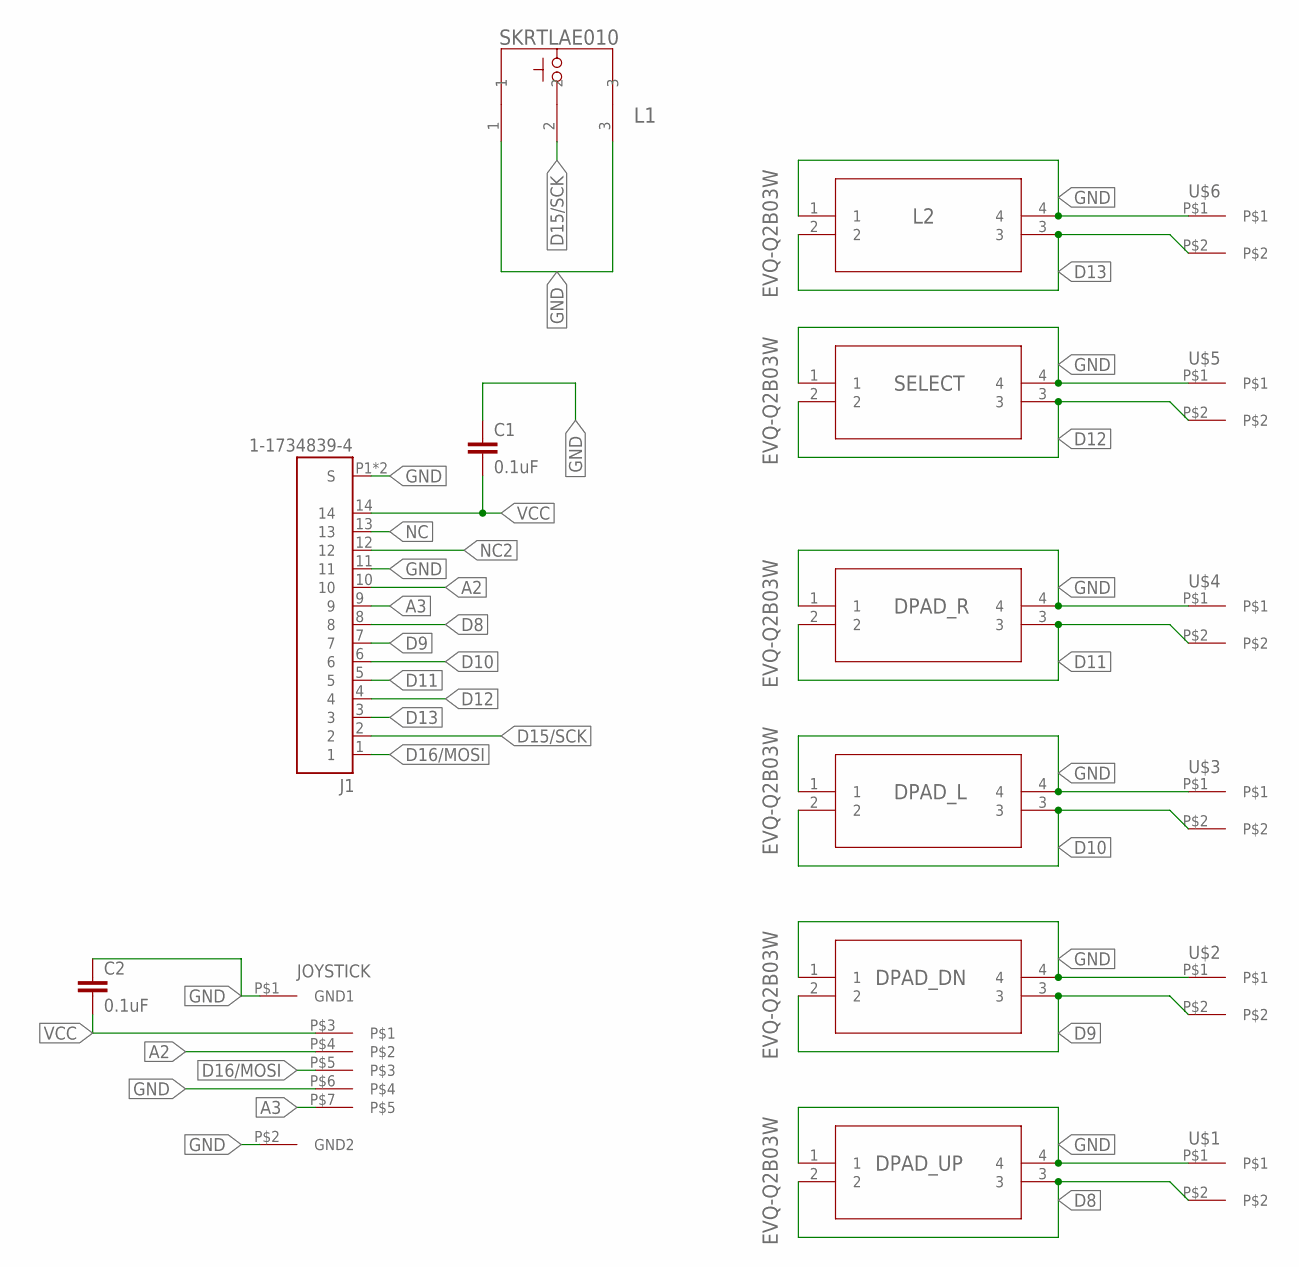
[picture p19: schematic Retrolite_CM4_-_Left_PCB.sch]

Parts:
C1, C2: 0.1uF; 0603
DPAD_DN: EVQ-Q2B03W; EVQQ2_3
DPAD_L: EVQ-Q2B03W; EVQQ2_3
DPAD_R: EVQ-Q2B03W; EVQQ2_3
DPAD_UP: EVQ-Q2B03W; EVQQ2_3
J1: 1-1734839-4; TE_1-1734839-4
JOYSTICK: 0545500571
L1: SKRTLAE010; SW3_SKRTLAE010_ALPS
L2: EVQ-Q2B03W; EVQQ2_3
SELECT: EVQ-Q2B03W; EVQQ2_3
U$1, U$2, U$3, U$4, U$5, U$6: MEMBRANEBUTTON

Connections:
A2: J1.10, JOYSTICK.P$4
A3: J1.9, JOYSTICK.P$7
D8: DPAD_UP.2, DPAD_UP.3, J1.8, U$1.P$2
D9: DPAD_DN.2, DPAD_DN.3, J1.7, U$2.P$2
D10: DPAD_L.2, DPAD_L.3, J1.6, U$3.P$2
D11: DPAD_R.2, DPAD_R.3, J1.5, U$4.P$2
D12: J1.4, SELECT.2, SELECT.3, U$5.P$2
D13: J1.3, L2.2, L2.3, U$6.P$2
D15/SCK: J1.2, L1.2
D16/MOSI: J1.1, JOYSTICK.P$5
GND: C1.1, C2.1, DPAD_DN.1, DPAD_DN.4, DPAD_L.1, DPAD_L.4, DPAD_R.1, DPAD_R.4, DPAD_UP.1, DPAD_UP.4, J1.11, J1.P1 (S), J1.P2 (S), JOYSTICK.P$1 (GND1), JOYSTICK.P$2 (GND2), JOYSTICK.P$6, L1.1, L1.3, L2.1, L2.4, SELECT.1, SELECT.4, U$1.P$1, U$2.P$1, U$3.P$1, U$4.P$1, U$5.P$1, U$6.P$1
NC: J1.13
NC2: J1.12
VCC: C1.2, C2.2, J1.14, JOYSTICK.P$3

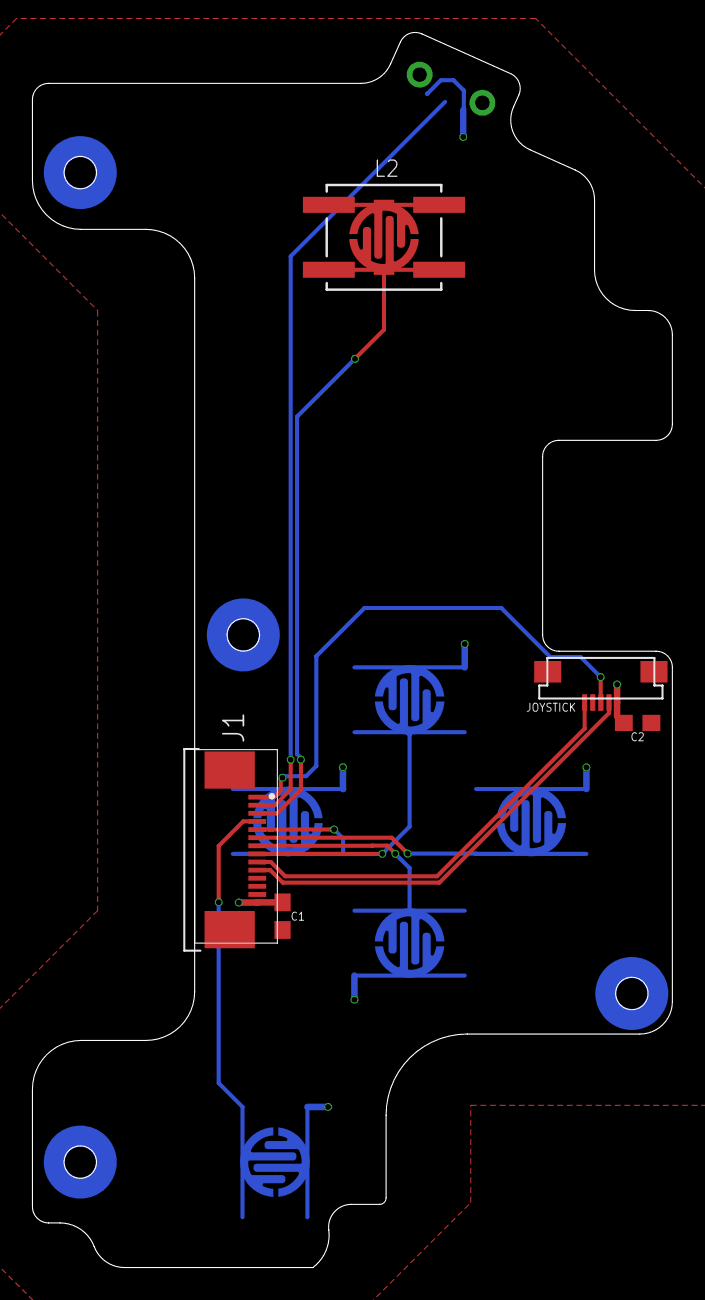
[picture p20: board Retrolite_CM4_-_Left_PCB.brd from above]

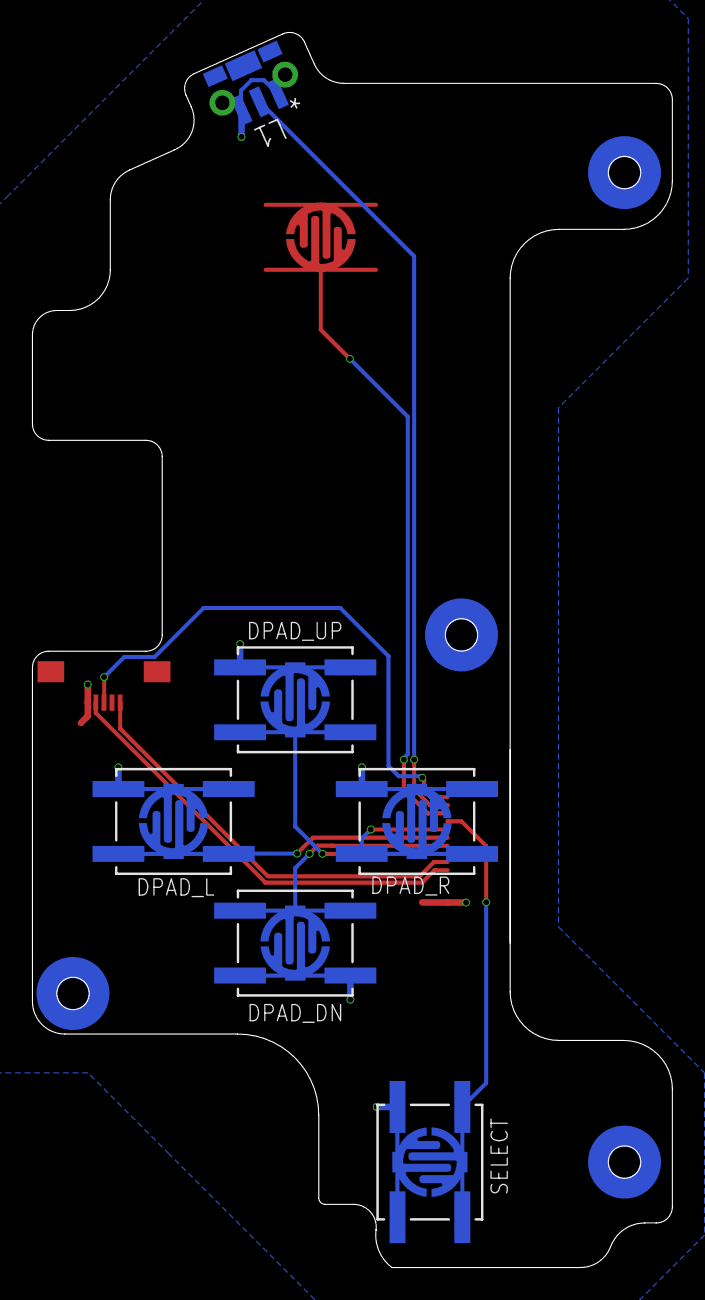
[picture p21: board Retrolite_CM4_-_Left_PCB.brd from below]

Board: 2 copper layers, 39.5 x 76.1 mm, 17 parts (11 on the bottom side), 12 nets.

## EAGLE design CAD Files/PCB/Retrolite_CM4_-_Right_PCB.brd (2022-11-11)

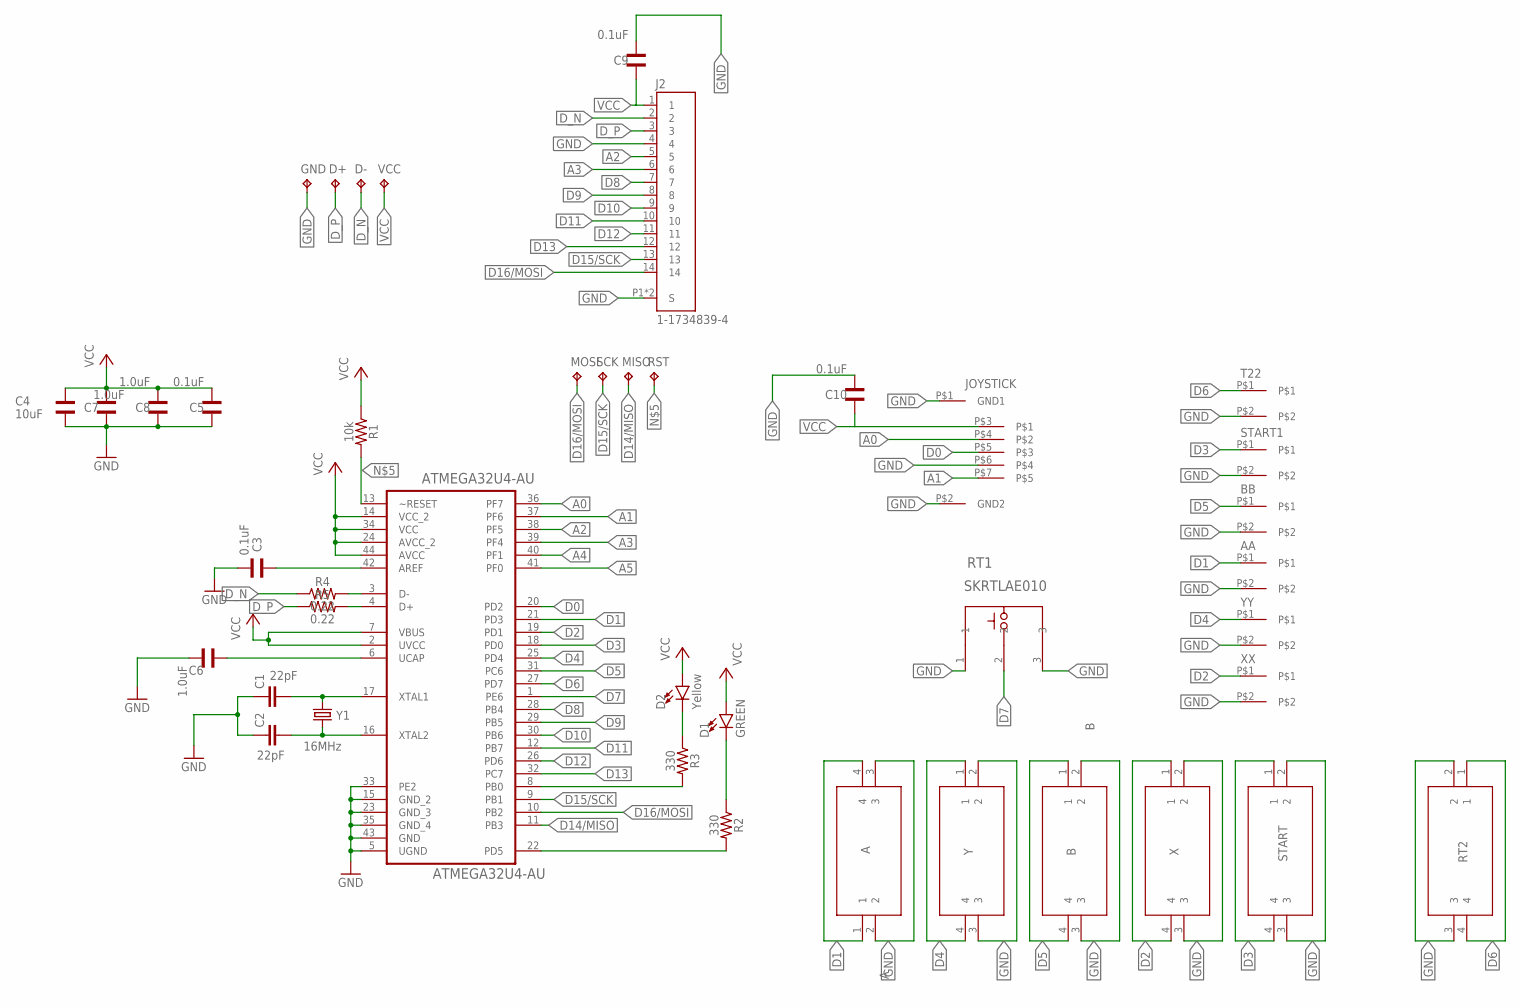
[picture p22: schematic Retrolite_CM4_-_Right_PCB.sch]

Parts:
A: A; EVQQ2_3
AA: MEMBRANEBUTTON
ATMEGA32U4-AU: ATMEGA32U4-AU; QFP80P1200X1200X120-44N
B: B; EVQQ2_3
BB: MEMBRANEBUTTON
C1, C2: 22pF; 0603
C3, C5, C9, C10: 0.1uF; WCAP-CSGP_0805_WAVE
C4: 10uF; WCAP-CSGP_0805_WAVE
C6, C7, C8: 1.0uF; WCAP-CSGP_0805_WAVE
D1: GREEN; LED-0603
D2: Yellow; LED-0603
D+: TPB1,27; B1,27
D-: TPB1,27; B1,27
GND: TPB1,27; B1,27
J2: 1-1734839-4; TE_1-1734839-4
JOYSTICK: 0545500571
MISO: TPB1,27; B1,27
MOSI: TPB1,27; B1,27
R1: 10k; 0603
R2, R3: 330; 0603
R4, R5: 0.22; 0805
RST: TPB1,27; B1,27
RT1: SKRTLAE010; SW3_SKRTLAE010_ALPS
RT2: T2; EVQQ2_3
SCK: TPB1,27; B1,27
START: START; EVQQ2_3
START1: MEMBRANEBUTTON
T22: MEMBRANEBUTTON
VCC: TPB1,27; B1,27
X: X; EVQQ2_3
XX: MEMBRANEBUTTON
Y: Y; EVQQ2_3
Y1: 16MHz; CRYSTAL-SMD-5X3.2-4PAD
YY: MEMBRANEBUTTON

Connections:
A0: ATMEGA32U4-AU.36 (PF7), JOYSTICK.P$4
A1: ATMEGA32U4-AU.37 (PF6), JOYSTICK.P$7
A2: ATMEGA32U4-AU.38 (PF5), J2.5
A3: ATMEGA32U4-AU.39 (PF4), J2.6
A4: ATMEGA32U4-AU.40 (PF1)
A5: ATMEGA32U4-AU.41 (PF0)
D0: ATMEGA32U4-AU.20 (PD2), JOYSTICK.P$5
D1: A.1, A.4, AA.P$1, ATMEGA32U4-AU.21 (PD3)
D2: ATMEGA32U4-AU.19 (PD1), X.1, X.4, XX.P$1
D3: ATMEGA32U4-AU.18 (PD0), START.1, START.4, START1.P$1
D4: ATMEGA32U4-AU.25 (PD4), Y.1, Y.4, YY.P$1
D5: ATMEGA32U4-AU.31 (PC6), B.1, B.4, BB.P$1
D6: ATMEGA32U4-AU.27 (PD7), RT2.1, RT2.4, T22.P$1
D7: ATMEGA32U4-AU.1 (PE6), RT1.2
D8: ATMEGA32U4-AU.28 (PB4), J2.7
D9: ATMEGA32U4-AU.29 (PB5), J2.8
D10: ATMEGA32U4-AU.30 (PB6), J2.9
D11: ATMEGA32U4-AU.12 (PB7), J2.10
D12: ATMEGA32U4-AU.26 (PD6), J2.11
D13: ATMEGA32U4-AU.32 (PC7), J2.12
D14/MISO: ATMEGA32U4-AU.11 (PB3), MISO.TP
D15/SCK: ATMEGA32U4-AU.9 (PB1), J2.13, SCK.TP
D16/MOSI: ATMEGA32U4-AU.10 (PB2), J2.14, MOSI.TP
D_N: D-.TP, J2.2, R4.1
D_P: D+.TP, J2.3, R5.1
GND: A.2, A.3, AA.P$2, ATMEGA32U4-AU.5 (UGND), ATMEGA32U4-AU.15 (GND_2), ATMEGA32U4-AU.23 (GND_3), ATMEGA32U4-AU.33 (PE2), ATMEGA32U4-AU.35 (GND_4), ATMEGA32U4-AU.43 (GND), B.2, B.3, BB.P$2, C1.1, C2.1, C3.1, C4.1, C5.2, C6.1, C7.2, C8.2, C9.1, C10.1, GND.TP, J2.4, J2.P1 (S), J2.P2 (S), JOYSTICK.P$1 (GND1), JOYSTICK.P$2 (GND2), JOYSTICK.P$6, RT1.1, RT1.3, RT2.2, RT2.3, START.2, START.3, START1.P$2, T22.P$2, X.2, X.3, XX.P$2, Y.2, Y.3, YY.P$2
unnamed: ATMEGA32U4-AU.17 (XTAL1), C1.2, Y1.1
unnamed: ATMEGA32U4-AU.42 (AREF), C3.2
unnamed: ATMEGA32U4-AU.6 (UCAP), C6.2
unnamed: ATMEGA32U4-AU.16 (XTAL2), C2.2, Y1.3 (2)
unnamed: ATMEGA32U4-AU.13 (~RESET), R1.2, RST.TP
unnamed: ATMEGA32U4-AU.22 (PD5), R2.2
unnamed: ATMEGA32U4-AU.8 (PB0), R3.2
unnamed: D1.C, R2.1
unnamed: D2.C, R3.1
USB_N: ATMEGA32U4-AU.3 (D-), R4.2
USB_P: ATMEGA32U4-AU.4 (D+), R5.2
VCC: ATMEGA32U4-AU.2 (UVCC), ATMEGA32U4-AU.7 (VBUS), ATMEGA32U4-AU.14 (VCC_2), ATMEGA32U4-AU.24 (AVCC_2), ATMEGA32U4-AU.34 (VCC), ATMEGA32U4-AU.44 (AVCC), C4.2, C5.1, C7.1, C8.1, C9.2, C10.2, D1.A, D2.A, J2.1, JOYSTICK.P$3, R1.1, VCC.TP

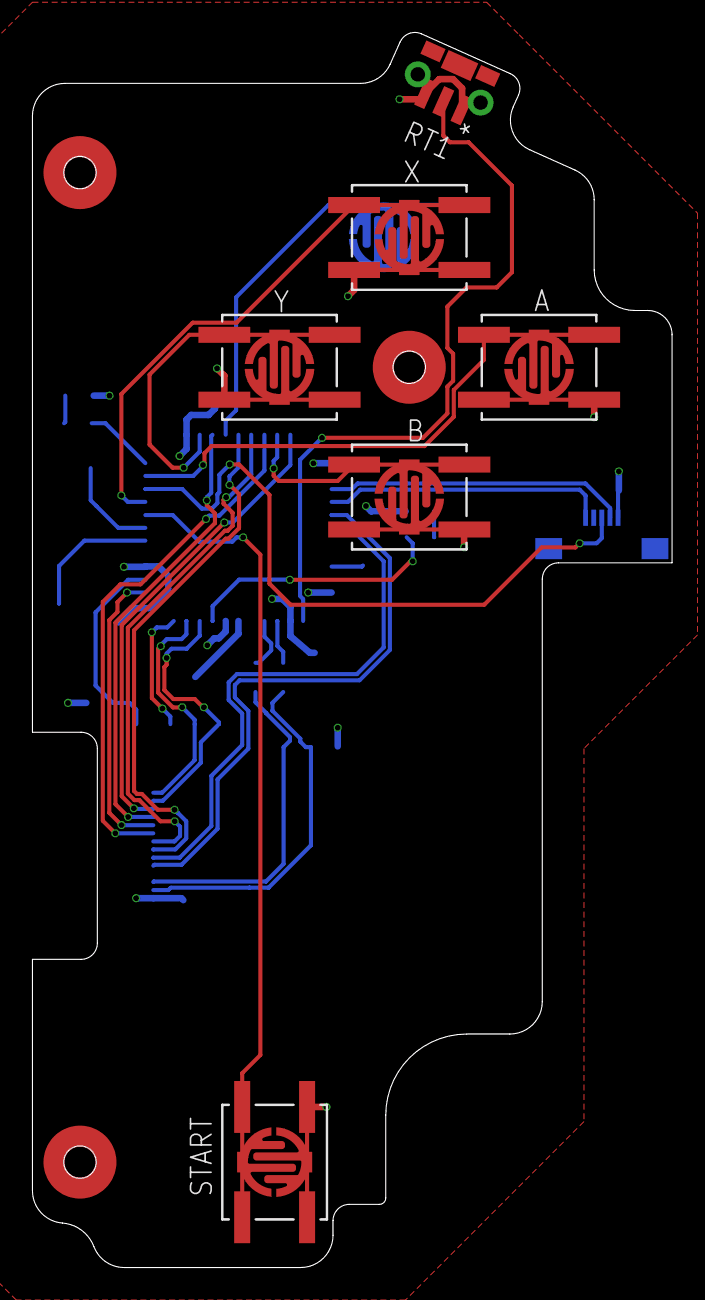
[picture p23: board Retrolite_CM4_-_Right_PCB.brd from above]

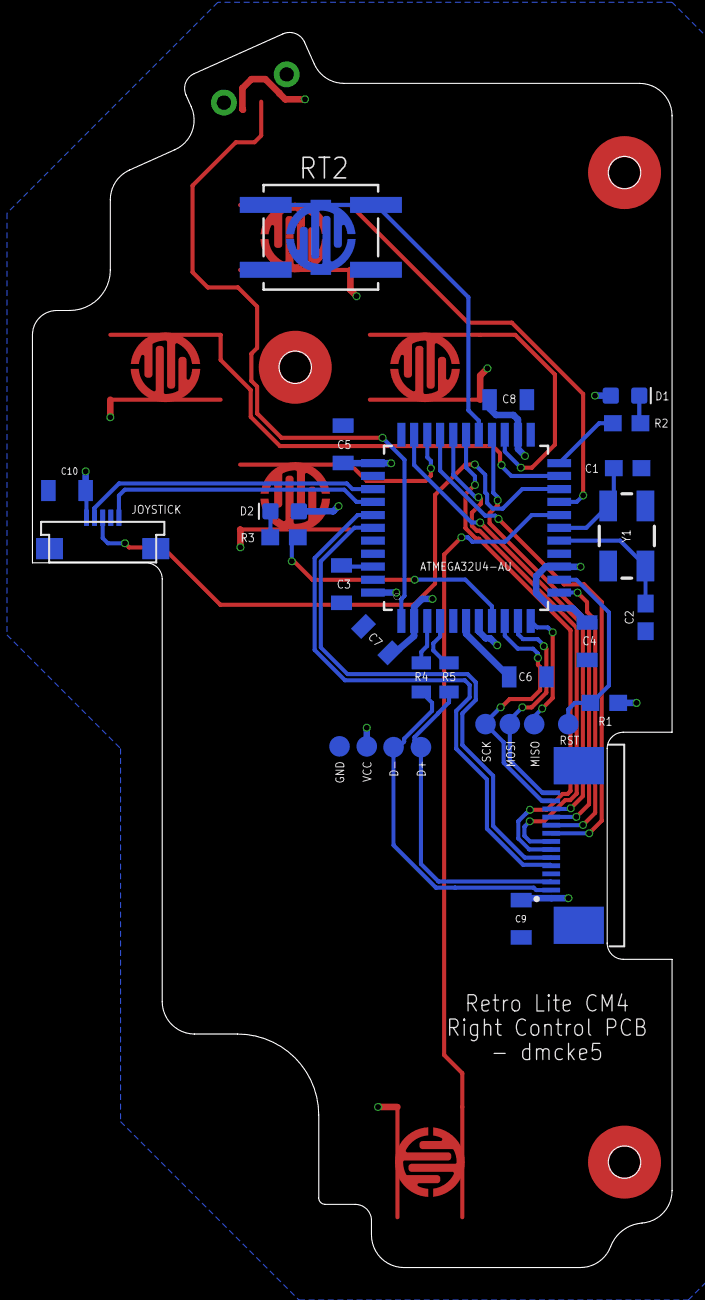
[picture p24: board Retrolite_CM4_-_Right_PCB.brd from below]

Board: 2 copper layers, 39.4 x 76.1 mm, 42 parts (31 on the bottom side), 36 nets.

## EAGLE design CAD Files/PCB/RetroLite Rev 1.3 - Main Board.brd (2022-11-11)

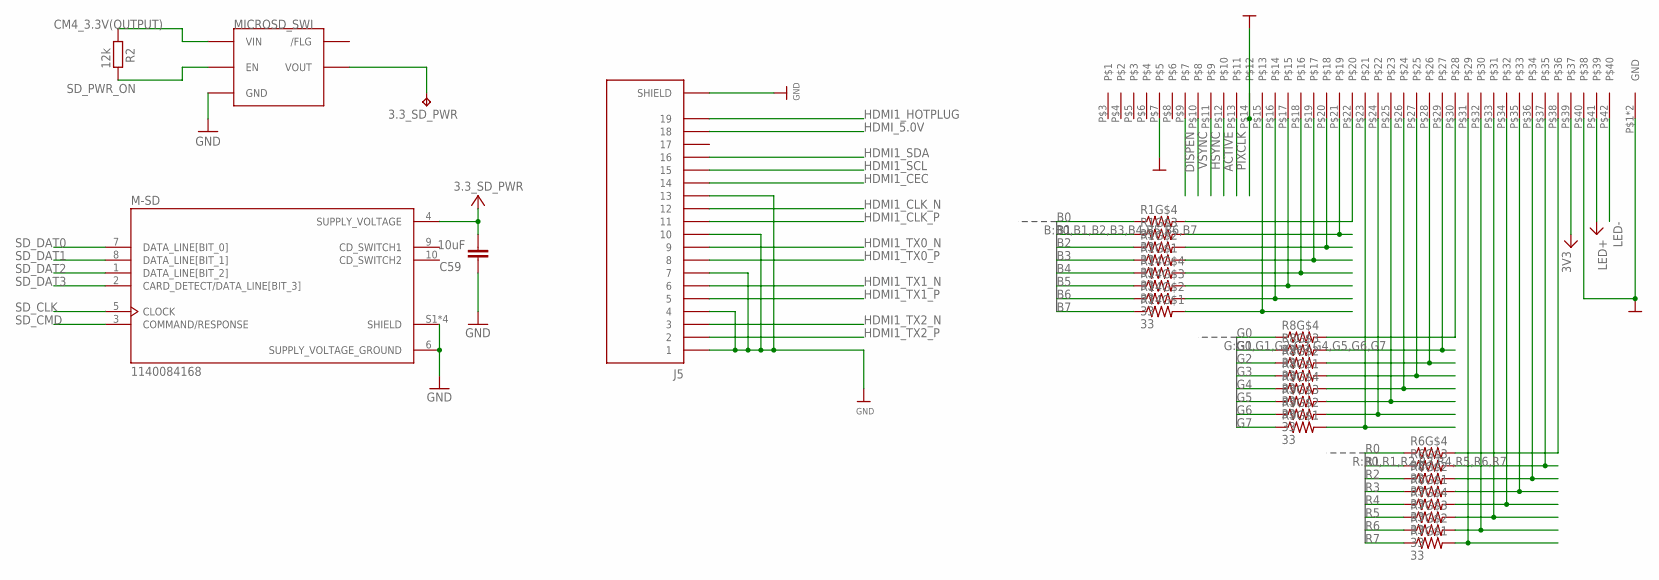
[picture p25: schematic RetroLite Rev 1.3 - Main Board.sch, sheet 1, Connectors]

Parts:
3.3_SD_PWR: TPTP07R; TP07R
C59: 10uF; 0805
J5: 685119136923; WURTH_685119136923
M-SD: 1140084168; AMPHENOL_1140084168
MICROSD_SWI: IC-RT9742
R1, R6, R7, R8, R9, R14: 33; RESPACK_4X0603
R2: 12k; R0603
U3: S62684-402100ALF

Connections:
3.3_SD_PWR: 3.3_SD_PWR.TP, C59.2, M-SD.4 (SUPPLY_VOLTAGE), MICROSD_SWI.VOUT
3V3: U3.P$39; also elsewhere on the board
ACTIVE: U3.P$12; also elsewhere on the board
B0: R1.4 (1); also elsewhere on the board
B1: R1.3 (1); also elsewhere on the board
B2: R1.2 (1); also elsewhere on the board
B3: R1.1; also elsewhere on the board
B4: R14.4 (1); also elsewhere on the board
B5: R14.3 (1); also elsewhere on the board
B6: R14.2 (1); also elsewhere on the board
B7: R14.1; also elsewhere on the board
CM4_3.3V(OUTPUT): MICROSD_SWI.VIN, R2.1; also elsewhere on the board
DISPEN: U3.P$9; also elsewhere on the board
G0: R8.4 (1); also elsewhere on the board
G1: R8.3 (1); also elsewhere on the board
G2: R8.2 (1); also elsewhere on the board
G3: R8.1; also elsewhere on the board
G4: R9.4 (1); also elsewhere on the board
G5: R9.3 (1); also elsewhere on the board
G6: R9.2 (1); also elsewhere on the board
G7: R9.1; also elsewhere on the board
GND: C59.1, J5.1, J5.4, J5.7, J5.10, J5.13, J5.S1 (SHIELD), J5.S2 (SHIELD), J5.S3 (SHIELD), J5.S4 (SHIELD), M-SD.6 (SUPPLY_VOLTAGE_GROUND), M-SD.S1 (SHIELD), M-SD.S2 (SHIELD), M-SD.S3 (SHIELD), M-SD.S4 (SHIELD), MICROSD_SWI.GND, U3.P$1 (GND), U3.P$2 (GND), U3.P$7, U3.P$14, U3.P$40; also elsewhere on the board
HDMI1_CEC: J5.14; also elsewhere on the board
HDMI1_CLK_N: J5.12; also elsewhere on the board
HDMI1_CLK_P: J5.11; also elsewhere on the board
HDMI1_HOTPLUG: J5.19; also elsewhere on the board
HDMI1_SCL: J5.15; also elsewhere on the board
HDMI1_SDA: J5.16; also elsewhere on the board
HDMI1_TX0_N: J5.9; also elsewhere on the board
HDMI1_TX0_P: J5.8; also elsewhere on the board
HDMI1_TX1_N: J5.6; also elsewhere on the board
HDMI1_TX1_P: J5.5; also elsewhere on the board
HDMI1_TX2_N: J5.3; also elsewhere on the board
HDMI1_TX2_P: J5.2; also elsewhere on the board
HDMI_5.0V: J5.18; also elsewhere on the board
HSYNC: U3.P$11; also elsewhere on the board
LED+: U3.P$41; also elsewhere on the board
LED-: U3.P$42; also elsewhere on the board
unnamed: R8.5 (2), U3.P$30
unnamed: R8.6 (2), U3.P$29
unnamed: R8.7 (2), U3.P$28
unnamed: R8.8 (2), U3.P$27
unnamed: R9.5 (2), U3.P$26
unnamed: R9.6 (2), U3.P$25
unnamed: R6.5 (2), U3.P$38
unnamed: R6.6 (2), U3.P$37
unnamed: R6.7 (2), U3.P$36
unnamed: R6.8 (2), U3.P$35
unnamed: R7.5 (2), U3.P$34
unnamed: R7.6 (2), U3.P$33
unnamed: R7.7 (2), U3.P$32
unnamed: R7.8 (2), U3.P$31
unnamed: R9.7 (2), U3.P$24
unnamed: R9.8 (2), U3.P$23
unnamed: R1.5 (2), U3.P$22
unnamed: R1.6 (2), U3.P$21
unnamed: R1.7 (2), U3.P$20
unnamed: R1.8 (2), U3.P$19
unnamed: R14.8 (2), U3.P$15
unnamed: R14.7 (2), U3.P$16
unnamed: R14.6 (2), U3.P$17
unnamed: R14.5 (2), U3.P$18
PIXCLK: U3.P$13; also elsewhere on the board
R0: R6.4 (1); also elsewhere on the board
R1: R6.3 (1); also elsewhere on the board
R2: R6.2 (1); also elsewhere on the board
R3: R6.1; also elsewhere on the board
R4: R7.4 (1); also elsewhere on the board
R5: R7.3 (1); also elsewhere on the board
R6: R7.2 (1); also elsewhere on the board
R7: R7.1; also elsewhere on the board
SD_CLK: M-SD.5 (CLOCK); also elsewhere on the board
SD_CMD: M-SD.3 (COMMAND/RESPONSE); also elsewhere on the board
SD_DAT0: M-SD.7 (DATA_LINE[BIT_0]); also elsewhere on the board
SD_DAT1: M-SD.8 (DATA_LINE[BIT_1]); also elsewhere on the board
SD_DAT2: M-SD.1 (DATA_LINE[BIT_2]); also elsewhere on the board
SD_DAT3: M-SD.2 (CARD_DETECT/DATA_LINE[BIT_3]); also elsewhere on the board
SD_PWR_ON: MICROSD_SWI.EN, R2.2; also elsewhere on the board
VSYNC: U3.P$10; also elsewhere on the board

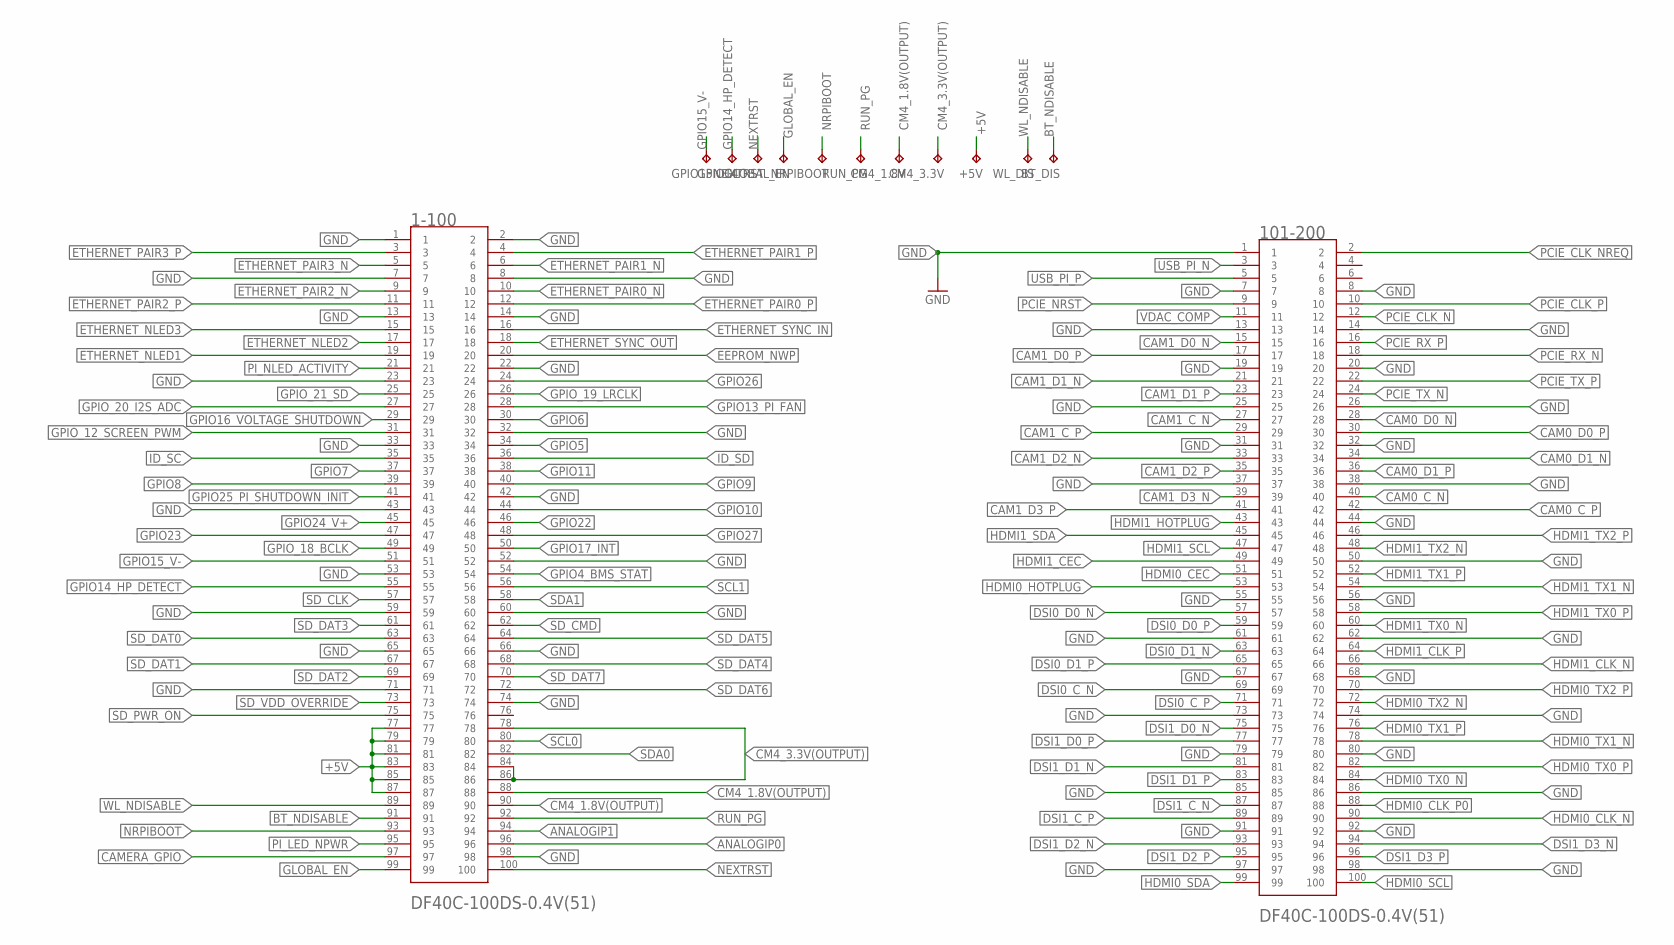
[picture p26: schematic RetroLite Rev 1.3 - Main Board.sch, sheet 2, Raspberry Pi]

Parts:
1-100, 101-200: DF40C-100DS-0.4V(51); HRS_DF40C-100DS-0.4V(51)
+5V: TPTP07R; TP07R
BT_DIS: TPTP07R; TP07R
CM4_1.8V, CM4_3.3V: TPTP07R; TP07R
GLOBAL_EN: TPTP07R; TP07R
GPIO14, GPIO15: TPTP07R; TP07R
NEXTRST: TPTP07R; TP07R
NRPIBOOT: TPTP07R; TP07R
RUN_PG: TPTP07R; TP07R
WL_DIS: TPTP07R; TP07R

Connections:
+5V: 1-100.77, 1-100.79, 1-100.81, 1-100.83, 1-100.85, 1-100.87, +5V.TP; also elsewhere on the board
ANALOGIP0: 1-100.96
ANALOGIP1: 1-100.94
BT_NDISABLE: 1-100.91, BT_DIS.TP
CAM0_C_N: 101-200.40
CAM0_C_P: 101-200.42
CAM0_D0_N: 101-200.28
CAM0_D0_P: 101-200.30
CAM0_D1_N: 101-200.34
CAM0_D1_P: 101-200.36
CAM1_C_N: 101-200.27
CAM1_C_P: 101-200.29
CAM1_D0_N: 101-200.15
CAM1_D0_P: 101-200.17
CAM1_D1_N: 101-200.21
CAM1_D1_P: 101-200.23
CAM1_D2_N: 101-200.33
CAM1_D2_P: 101-200.35
CAM1_D3_N: 101-200.39
CAM1_D3_P: 101-200.41
CAMERA_GPIO: 1-100.97
CM4_1.8V(OUTPUT): 1-100.88, 1-100.90, CM4_1.8V.TP
CM4_3.3V(OUTPUT): 1-100.78, 1-100.84, 1-100.86, CM4_3.3V.TP; also elsewhere on the board
DSI0_C_N: 101-200.69
DSI0_C_P: 101-200.71
DSI0_D0_N: 101-200.57
DSI0_D0_P: 101-200.59
DSI0_D1_N: 101-200.63
DSI0_D1_P: 101-200.65
DSI1_C_N: 101-200.87
DSI1_C_P: 101-200.89
DSI1_D0_N: 101-200.75
DSI1_D0_P: 101-200.77
DSI1_D1_N: 101-200.81
DSI1_D1_P: 101-200.83
DSI1_D2_N: 101-200.93
DSI1_D2_P: 101-200.95
DSI1_D3_N: 101-200.94
DSI1_D3_P: 101-200.96
EEPROM_NWP: 1-100.20
ETHERNET_NLED1: 1-100.19
ETHERNET_NLED2: 1-100.17
ETHERNET_NLED3: 1-100.15
ETHERNET_PAIR0_N: 1-100.10
ETHERNET_PAIR0_P: 1-100.12
ETHERNET_PAIR1_N: 1-100.6
ETHERNET_PAIR1_P: 1-100.4
ETHERNET_PAIR2_N: 1-100.9
ETHERNET_PAIR2_P: 1-100.11
ETHERNET_PAIR3_N: 1-100.5
ETHERNET_PAIR3_P: 1-100.3
ETHERNET_SYNC_IN: 1-100.16
ETHERNET_SYNC_OUT: 1-100.18
GLOBAL_EN: 1-100.99, GLOBAL_EN.TP; also elsewhere on the board
GND: 1-100.1, 1-100.2, 1-100.7, 1-100.8, 1-100.13, 1-100.14, 1-100.22, 1-100.23, 1-100.32, 1-100.33, 1-100.42, 1-100.43, 1-100.52, 1-100.53, 1-100.59, 1-100.60, 1-100.65, 1-100.66, 1-100.71, 1-100.74, 1-100.98, 101-200.1, 101-200.7, 101-200.8, 101-200.13, 101-200.14, 101-200.19, 101-200.20, 101-200.25, 101-200.26, 101-200.31, 101-200.32, 101-200.37, 101-200.38, 101-200.44, 101-200.50, 101-200.55, 101-200.56, 101-200.61, 101-200.62, 101-200.67, 101-200.68, 101-200.73, 101-200.74, 101-200.79, 101-200.80, 101-200.85, 101-200.86, 101-200.91, 101-200.92, 101-200.97, 101-200.98; also elsewhere on the board
GPIO4_BMS_STAT: 1-100.54; also elsewhere on the board
GPIO5: 1-100.34
GPIO6: 1-100.30
GPIO7: 1-100.37
GPIO8: 1-100.39
GPIO9: 1-100.40
GPIO10: 1-100.44
GPIO11: 1-100.38
GPIO13_PI_FAN: 1-100.28; also elsewhere on the board
GPIO14_HP_DETECT: 1-100.55, GPIO14.TP; also elsewhere on the board
GPIO15_V-: 1-100.51, GPIO15.TP; also elsewhere on the board
GPIO16_VOLTAGE_SHUTDOWN: 1-100.29; also elsewhere on the board
GPIO17_INT: 1-100.50; also elsewhere on the board
GPIO22: 1-100.46
GPIO23: 1-100.47
GPIO24_V+: 1-100.45; also elsewhere on the board
GPIO25_PI_SHUTDOWN_INIT: 1-100.41; also elsewhere on the board
GPIO26: 1-100.24
GPIO27: 1-100.48
GPIO_12_SCREEN_PWM: 1-100.31; also elsewhere on the board
GPIO_18_BCLK: 1-100.49; also elsewhere on the board
GPIO_19_LRCLK: 1-100.26; also elsewhere on the board
GPIO_20_I2S_ADC: 1-100.27; also elsewhere on the board
GPIO_21_SD: 1-100.25; also elsewhere on the board
HDMI0_CEC: 101-200.51
HDMI0_CLK_N: 101-200.90; also elsewhere on the board
HDMI0_CLK_P0: 101-200.88; also elsewhere on the board
HDMI0_HOTPLUG: 101-200.53
HDMI0_SCL: 101-200.100; also elsewhere on the board
HDMI0_SDA: 101-200.99; also elsewhere on the board
HDMI0_TX0_N: 101-200.84; also elsewhere on the board
HDMI0_TX0_P: 101-200.82; also elsewhere on the board
HDMI0_TX1_N: 101-200.78; also elsewhere on the board
HDMI0_TX1_P: 101-200.76; also elsewhere on the board
HDMI0_TX2_N: 101-200.72; also elsewhere on the board
HDMI0_TX2_P: 101-200.70; also elsewhere on the board
HDMI1_CEC: 101-200.49; also elsewhere on the board
HDMI1_CLK_N: 101-200.66; also elsewhere on the board
HDMI1_CLK_P: 101-200.64; also elsewhere on the board
HDMI1_HOTPLUG: 101-200.43; also elsewhere on the board
HDMI1_SCL: 101-200.47; also elsewhere on the board
HDMI1_SDA: 101-200.45; also elsewhere on the board
HDMI1_TX0_N: 101-200.60; also elsewhere on the board
HDMI1_TX0_P: 101-200.58; also elsewhere on the board
HDMI1_TX1_N: 101-200.54; also elsewhere on the board
HDMI1_TX1_P: 101-200.52; also elsewhere on the board
HDMI1_TX2_N: 101-200.48; also elsewhere on the board
HDMI1_TX2_P: 101-200.46; also elsewhere on the board
ID_SC: 1-100.35
ID_SD: 1-100.36
NEXTRST: 1-100.100, NEXTRST.TP
NRPIBOOT: 1-100.93, NRPIBOOT.TP
PCIE_CLK_N: 101-200.12
PCIE_CLK_NREQ: 101-200.2
PCIE_CLK_P: 101-200.10
PCIE_NRST: 101-200.9
PCIE_RX_N: 101-200.18
PCIE_RX_P: 101-200.16
PCIE_TX_N: 101-200.24
PCIE_TX_P: 101-200.22
PI_LED_NPWR: 1-100.95; also elsewhere on the board
PI_NLED_ACTIVITY: 1-100.21; also elsewhere on the board
RUN_PG: 1-100.92, RUN_PG.TP; also elsewhere on the board
SCL0: 1-100.80
SCL1: 1-100.56; also elsewhere on the board
SDA0: 1-100.82
SDA1: 1-100.58; also elsewhere on the board
SD_CLK: 1-100.57; also elsewhere on the board
SD_CMD: 1-100.62; also elsewhere on the board
SD_DAT0: 1-100.63; also elsewhere on the board
SD_DAT1: 1-100.67; also elsewhere on the board
SD_DAT2: 1-100.69; also elsewhere on the board
SD_DAT3: 1-100.61; also elsewhere on the board
SD_DAT4: 1-100.68
SD_DAT5: 1-100.64
SD_DAT6: 1-100.72
SD_DAT7: 1-100.70
SD_PWR_ON: 1-100.75; also elsewhere on the board
SD_VDD_OVERRIDE: 1-100.73
USB_PI_N: 101-200.3; also elsewhere on the board
USB_PI_P: 101-200.5; also elsewhere on the board
VDAC_COMP: 101-200.11
WL_NDISABLE: 1-100.89, WL_DIS.TP

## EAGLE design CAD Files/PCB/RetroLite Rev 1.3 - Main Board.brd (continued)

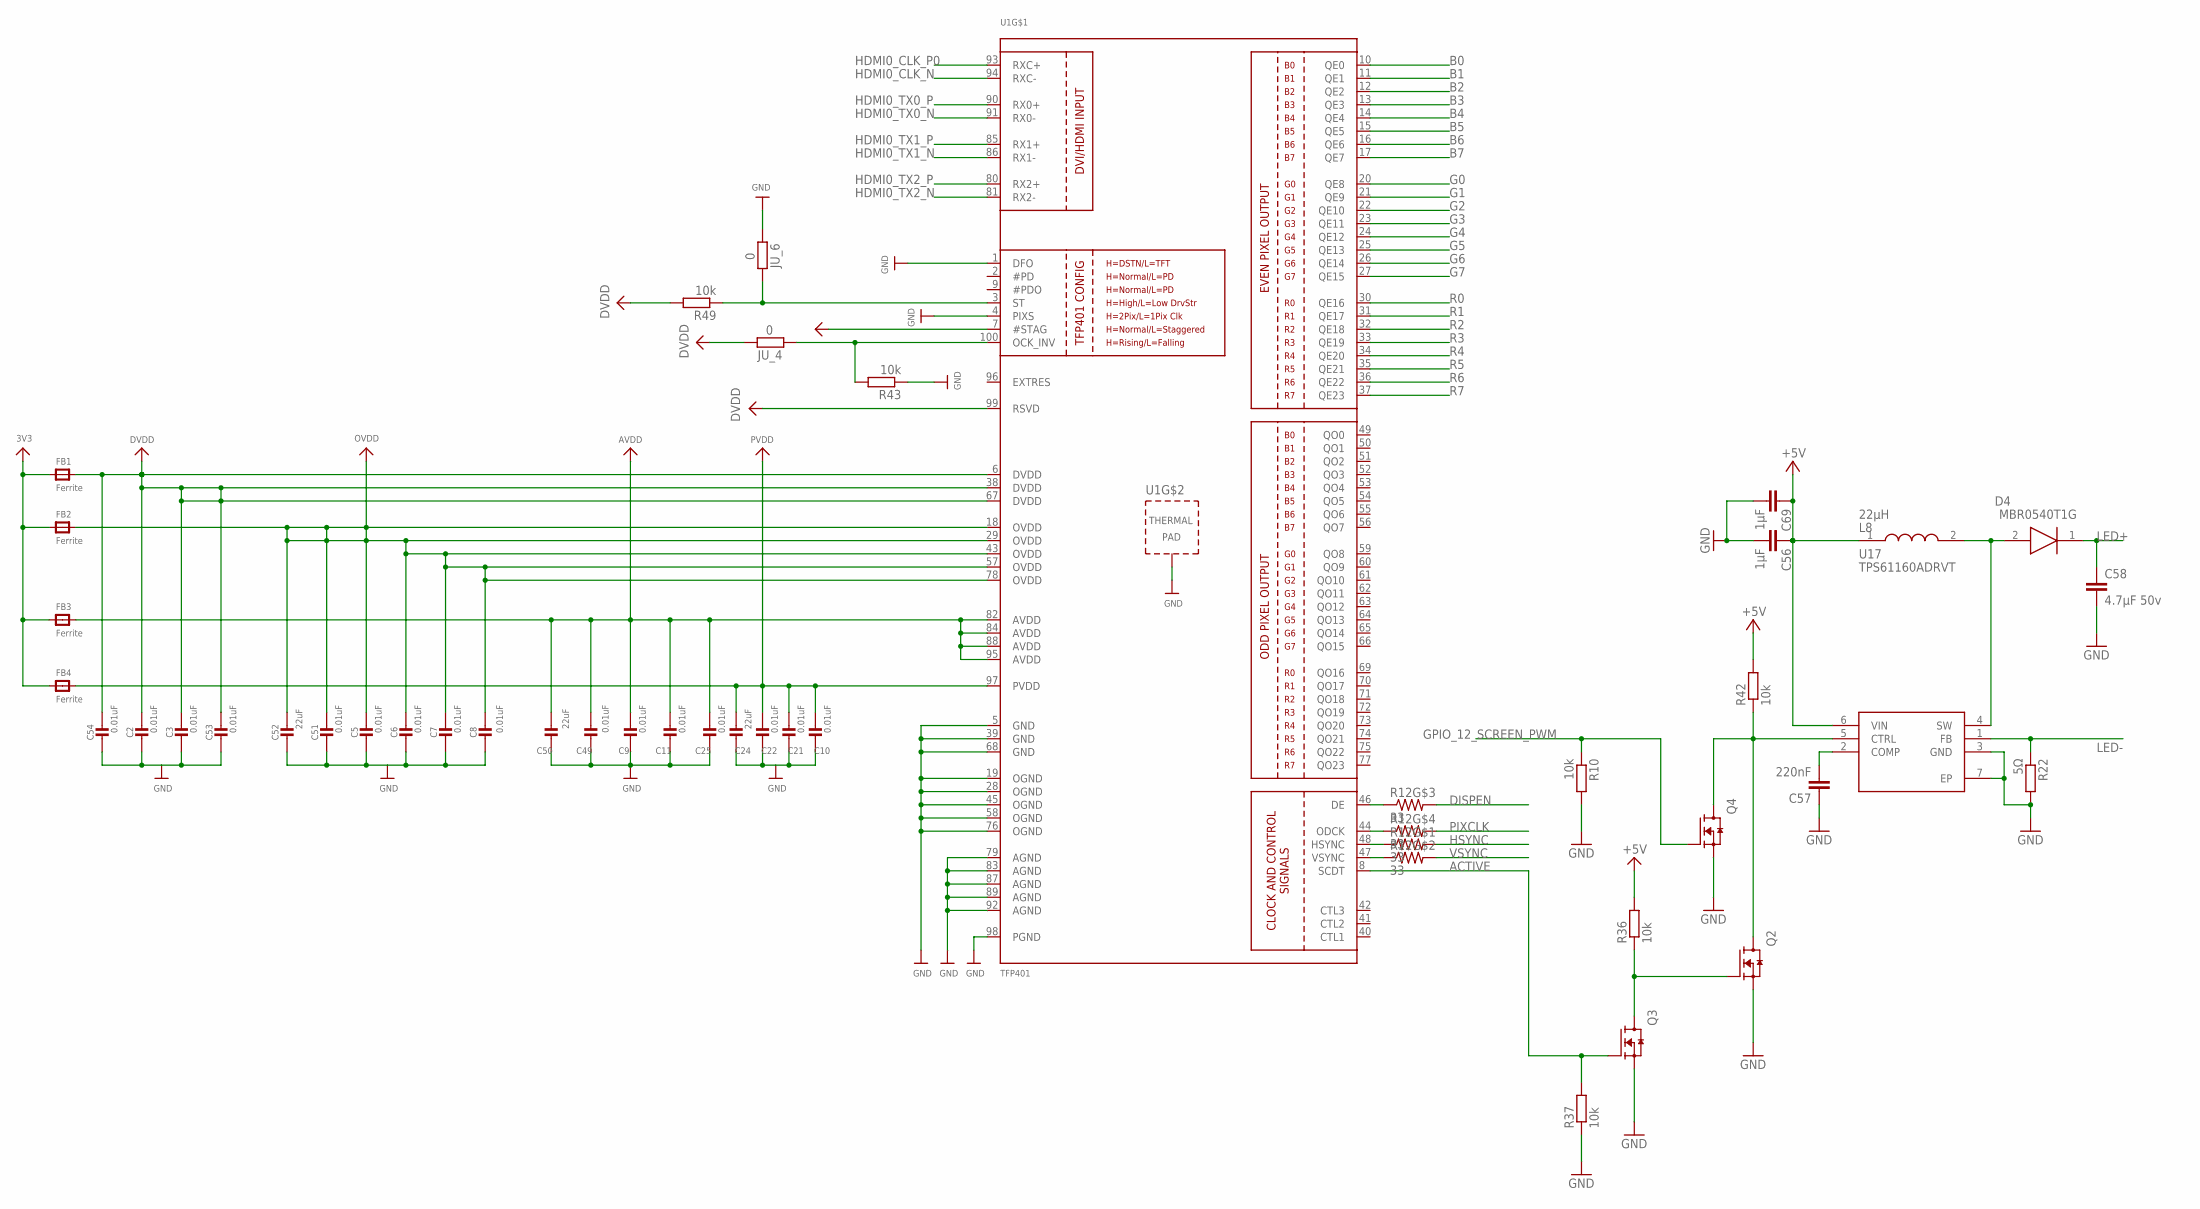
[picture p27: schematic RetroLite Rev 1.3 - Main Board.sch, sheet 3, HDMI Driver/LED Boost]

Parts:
C2, C3, C5, C6, C7, C8, C9, C10, C11, C21, C22, C25, C49, C51, C53, C54: 0.01uF; 0603-NO
C24, C50, C52: 22uF; 0603-NO
C56, C69: 1µF; C0603
C57: 220nF; C0603
C58: 4.7µF 50v; C0805
D4: MBR0540T1G; SOD3716X135N
FB1, FB2, FB3, FB4: Ferrite; _0805MP
JU_4, JU_6: 0; R0402
L8: 22µH; VLCF4020_1
Q2, Q3, Q4: AO3400A; SOT95P280X125-3N
R10, R36, R37, R42: 10k; R0603
R12: 33; RESPACK_4X0603
R22: 5Ω; R0603
R43, R49: 10k; R0402
U1: TFP401; S-PQFP-G100
U17: TPS61160ADRVT; SON65P200X200X80-7N

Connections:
3V3: FB1.1, FB2.1, FB3.1, FB4.1; also elsewhere on the board
+5V: C56.1, C69.1, L8.1, R36.2, R42.2, U17.6 (VIN); also elsewhere on the board
ACTIVE: Q3.1 (G), R37.2, U1.8 (SCDT); also elsewhere on the board
ASD: R12.3 (1), U1.46 (DE)
AVDD: C9.1, C11.1, C25.1, C49.1, C50.1, FB3.2, U1.82 (AVDD), U1.84 (AVDD), U1.88 (AVDD), U1.95 (AVDD)
B0: U1.10 (QE0); also elsewhere on the board
B1: U1.11 (QE1); also elsewhere on the board
B2: U1.12 (QE2); also elsewhere on the board
B3: U1.13 (QE3); also elsewhere on the board
B4: U1.14 (QE4); also elsewhere on the board
B5: U1.15 (QE5); also elsewhere on the board
B6: U1.16 (QE6); also elsewhere on the board
B7: U1.17 (QE7); also elsewhere on the board
CVB: R12.2 (1), U1.47 (VSYNC)
DISPEN: R12.6 (2); also elsewhere on the board
DVDD: C2.1, C3.1, C53.1, C54.1, FB1.2, JU_4.2, R49.2, U1.6 (DVDD), U1.7 (#STAG), U1.38 (DVDD), U1.67 (DVDD), U1.99 (RSVD)
G0: U1.20 (QE8); also elsewhere on the board
G1: U1.21 (QE9); also elsewhere on the board
G2: U1.22 (QE10); also elsewhere on the board
G3: U1.23 (QE11); also elsewhere on the board
G4: U1.24 (QE12); also elsewhere on the board
G5: U1.25 (QE13); also elsewhere on the board
G6: U1.26 (QE14); also elsewhere on the board
G7: U1.27 (QE15); also elsewhere on the board
GND: C2.2, C3.2, C5.2, C6.2, C7.2, C8.2, C9.2, C10.2, C11.2, C21.2, C22.2, C24.2, C25.2, C49.2, C50.2, C51.2, C52.2, C53.2, C54.2, C56.2, C57.1, C58.2, C69.2, JU_6.1, Q2.2 (S), Q3.2 (S), Q4.2 (S), R10.2, R22.2, R37.1, R43.1, U1.1 (DFO), U1.4 (PIXS), U1.5 (GND), U1.19 (OGND), U1.28 (OGND), U1.39 (GND), U1.45 (OGND), U1.58 (OGND), U1.68 (GND), U1.76 (OGND), U1.79 (AGND), U1.83 (AGND), U1.87 (AGND), U1.89 (AGND), U1.92 (AGND), U1.98 (PGND), U1.P$1 (TP), U1.P$2 (TP), U1.P$3 (TP), U1.P$4 (TP), U1.P$5 (TP), U1.P$6 (TP), U1.P$7 (TP), U1.P$8 (TP), U1.P$9 (TP), U1.P$10 (TP), U1.P$11 (TP), U1.P$12 (TP), U1.P$13 (TP), U1.P$14 (TP), U1.P$15 (TP), U1.P$16 (TP), U1.THERMAL (TP), U17.3 (GND), U17.7 (EP); also elsewhere on the board
GPIO_12_SCREEN_PWM: Q4.1 (G), R10.1; also elsewhere on the board
HDMI0_CLK_N: U1.94 (RXC-); also elsewhere on the board
HDMI0_CLK_P0: U1.93 (RXC+); also elsewhere on the board
HDMI0_TX0_N: U1.91 (RX0-); also elsewhere on the board
HDMI0_TX0_P: U1.90 (RX0+); also elsewhere on the board
HDMI0_TX1_N: U1.86 (RX1-); also elsewhere on the board
HDMI0_TX1_P: U1.85 (RX1+); also elsewhere on the board
HDMI0_TX2_N: U1.81 (RX2-); also elsewhere on the board
HDMI0_TX2_P: U1.80 (RX2+); also elsewhere on the board
HSYNC: R12.8 (2); also elsewhere on the board
LED+: C58.1, D4.1 (K); also elsewhere on the board
LED-: R22.1, U17.1 (FB); also elsewhere on the board
unnamed: C57.2, U17.2 (COMP)
unnamed: D4.2 (A), L8.2, U17.4 (SW)
unnamed: JU_4.1, R43.2, U1.100 (OCK_INV)
unnamed: Q2.3 (D), Q4.3 (D), R42.1, U17.5 (CTRL)
unnamed: Q2.1 (G), Q3.3 (D), R36.1
NEW: JU_6.2, R49.1, U1.3 (ST)
OVDD: C5.1, C6.1, C7.1, C8.1, C51.1, C52.1, FB2.2, U1.18 (OVDD), U1.29 (OVDD), U1.43 (OVDD), U1.57 (OVDD), U1.78 (OVDD)
PIXCLK: R12.5 (2); also elsewhere on the board
PVDD: C10.1, C21.1, C22.1, C24.1, FB4.2, U1.97 (PVDD)
R0: U1.30 (QE16); also elsewhere on the board
R1: U1.31 (QE17); also elsewhere on the board
R2: U1.32 (QE18); also elsewhere on the board
R3: U1.33 (QE19); also elsewhere on the board
R4: U1.34 (QE20); also elsewhere on the board
R5: U1.35 (QE21); also elsewhere on the board
R6: U1.36 (QE22); also elsewhere on the board
R7: U1.37 (QE23); also elsewhere on the board
VSYNC: R12.7 (2); also elsewhere on the board
XCV: R12.1, U1.48 (HSYNC)
ZXC: R12.4 (1), U1.44 (ODCK)

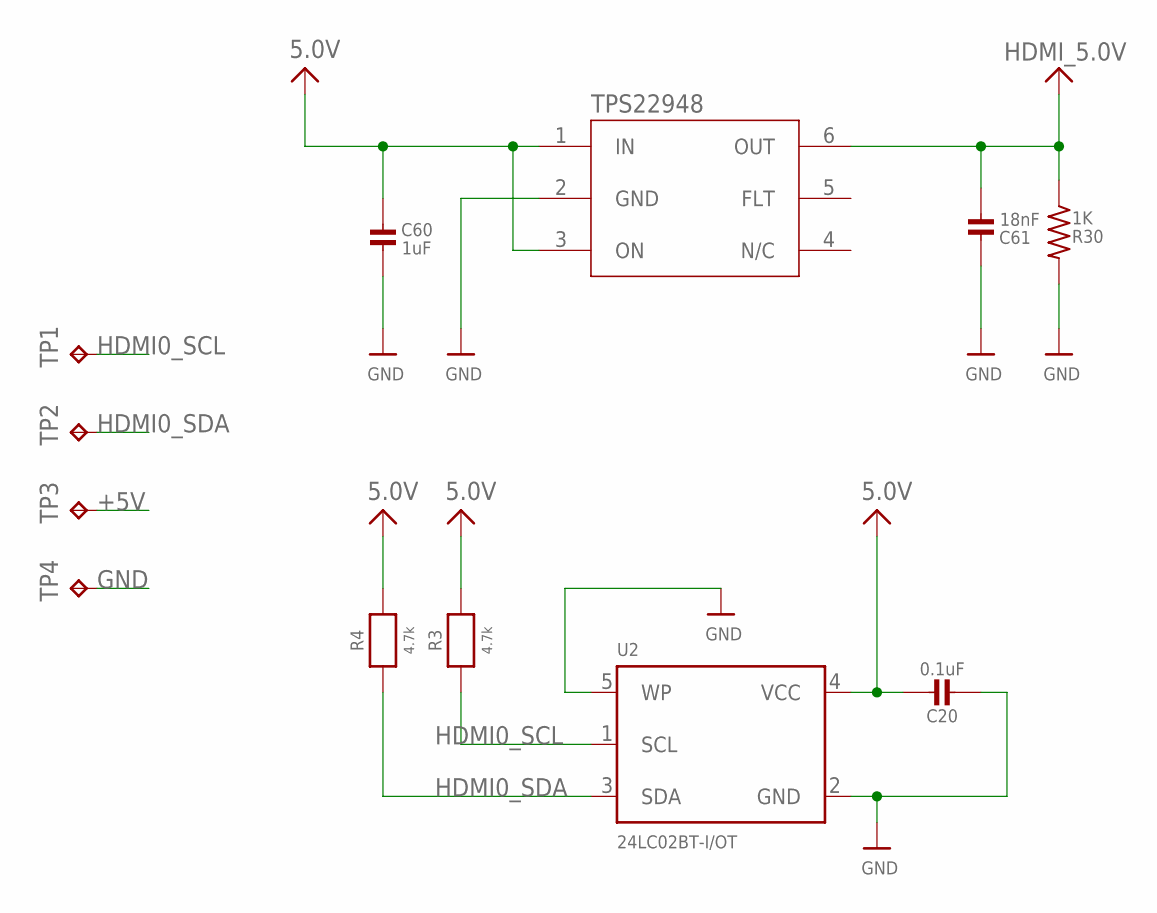
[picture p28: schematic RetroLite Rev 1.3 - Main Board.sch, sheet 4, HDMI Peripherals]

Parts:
C20: 0.1uF; 0603-NO
C60: 1uF; 0603-NO
C61: 18nF; 0603-NO
R3, R4: 4.7k; 0603-NO
R30: 1K; R0603
TP1, TP2, TP3, TP4: TPTP07R; TP07R
U2: 24LC02BT-I/OT; SOT23-5
U15: TPS22948; SOT65P210X110-6N

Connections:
+5V: C20.1, C60.1, R3.2, R4.2, TP3.TP, U2.4 (VCC), U15.1 (IN), U15.3 (ON); also elsewhere on the board
GND: C20.2, C60.2, C61.2, R30.2, TP4.TP, U2.2 (GND), U2.5 (WP), U15.2 (GND); also elsewhere on the board
HDMI0_SCL: R3.1, TP1.TP, U2.1 (SCL); also elsewhere on the board
HDMI0_SDA: R4.1, TP2.TP, U2.3 (SDA); also elsewhere on the board
HDMI_5.0V: C61.1, R30.1, U15.6 (OUT); also elsewhere on the board


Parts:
C1: 1µF; C0805
C4, C23, C27, C28, C31: 10µF; C0805
C29: 0.047µF; C0603
C30, C55: 1uF; C0603
J4: 78171-0005; MOLEX_78171-0005
L6: ASPI-0630HI
R41: 261Ω; R0603
R45, R46: 10kΩ; R0603
U5: BQ24292I; QFN50P400X400X100-25N

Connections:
BAT: C31.2, J4.4, J4.5, U5.13 (BAT), U5.14 (BAT); also elsewhere on the board
BMS_SDA/MOSI: U5.6 (SDA); also elsewhere on the board
BMS_STAT: U5.4 (STAT); also elsewhere on the board
BMS_SW: C29.1, L6.P$1 (1), U5.19 (SW), U5.20 (SW)
GND: C1.1, C4.1, C23.1, C27.1, C28.1, C30.1, C31.1, C55.1, R41.1, R45.1, U5.2 (PSEL), U5.8 (OTG), U5.9 (!CE), U5.17 (PGND), U5.18 (PGND), U5.25 (EPAD); also elsewhere on the board
unnamed: C55.2, U5.23 (PMID)
unnamed: C29.2, U5.21 (BTST)
unnamed: R41.2, U5.10 (ILIM)
PK-: J4.1, J4.2; also elsewhere on the board
REGN: C30.2, R46.2, U5.22 (REGN)
SCK/BMS_SCL: U5.5 (SCL); also elsewhere on the board
TS: R45.2, R46.1, U5.11 (TS1), U5.12 (TS2)
VBUS: C1.2, U5.1 (VBUS), U5.24 (VBUS); also elsewhere on the board
VSYS: C4.2, C23.2, C27.2, C28.2, L6.P$2 (2), U5.15 (SYS), U5.16 (SYS); also elsewhere on the board


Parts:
C33, C34: 1uF; C0805
C38: 1uF; C0603
C39: 100nF; C0603
C66, C67: 10uF; C0805
D2: ESDA25W; SOT65P210X110-3N
D3: ESDA25P35-1U1M; ESDA8P801U1M
J1: U262-161N-4BVC11
R11, R20: 5.1k; R0603
R21: 100k; R0603
SJ3: SOLDERJUMPER; SOLDERJUMPER_ARROW_NOPASTE
U7: IP2721; TSSOP-16

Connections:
3V3: C38.1, C39.1; also elsewhere on the board
BMS_STAT: J1.B8 (SBU2); also elsewhere on the board
CC1: D2.1 (K2), J1.A5 (CC1), R11.1, U7.13 (CC1)
CC2: D2.2 (K1), J1.B5 (CC2), R20.1, U7.12 (CC2)
D1_PORT_N: J1.A7 (D-_1), J1.B7 (D-_2); also elsewhere on the board
D1_PORT_P: J1.A6 (D+_1), J1.B6 (D+_2); also elsewhere on the board
GND: C33.2, C34.2, C38.2, C39.2, C66.1, C67.1, D2.3 (A), D3.1 (A), J1.A1B12 (GND), J1.B1A12 (GND), J1.SHIELD_1 (GND), J1.SHIELD_2 (GND), J1.SHIELD_3 (GND), J1.SHIELD_4 (GND), R11.2, R20.2, U7.5 (GND); also elsewhere on the board
unnamed: R21.2, SJ3.2
SBU1_DOCK: J1.A8 (SBU1); also elsewhere on the board
SEL: SJ3.1, U7.11 (SEL)
VBUS: C33.1, C34.1, C66.2, C67.2, D3.2 (C), J1.A4B9 (VBUS), J1.B4A9 (VBUS), R21.1, U7.2 (VIN), U7.16 (VBUS); also elsewhere on the board


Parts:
C68: 1.0uF; 0603
LEDN: TPTP07R; TP07R
LEDN_ACT: LEDSML0603; SML0603
LEDN_PWR: LEDSML0603; SML0603
R13: 1k; R0603
R44: 10k; R0603
R48: 2.2k; R0603
U22: BUF-74LVC1G07

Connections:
CM4_3.3V(OUTPUT): C68.2, LEDN_ACT.A, R44.1, R48.1, U22.VCC; also elsewhere on the board
GND: C68.1, U22.GND; also elsewhere on the board
unnamed: LEDN.TP, LEDN_ACT.C, R13.2
unnamed: LEDN_PWR.A, R48.2
unnamed: LEDN_PWR.C, R44.2, U22.Y
PI_LED_NPWR: U22.A; also elsewhere on the board
PI_NLED_ACTIVITY: R13.1; also elsewhere on the board


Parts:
C12, C13, C18, C26: 0.1uF; C0603
C14, C15, C16: 4.7uF; C0603
C35, C36: 100uF; C1206
J2: SJ-43516-SMT; CUI_SJ-43516-SMT
L+: TPSTP09SQ; TP09SQ
L-: TPSTP09SQ; TP09SQ
R15, R16, R17, R18, R19: 10R; R0603
R23: 10K; R0603
R+: TPSTP09SQ; TP09SQ
R-: TPSTP09SQ; TP09SQ
U6: WM8960; QFN50P500X500X100-33N
Y1: ECS-3225MV-240-BN-TR; OSC_ECS-2333-160-BN-TR

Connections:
+5V: C15.1, C16.1, U6.21 (SPKVDD2), U6.26 (SPKVDD1); also elsewhere on the board
ADC: R19.2, U6.16 (ADCDAT)
BCLK: R16.2, U6.12 (BCLK)
CM4_3.3V(OUTPUT): C12.1, C13.1, C18.2, C26.2, U6.8 (DCVDD), U6.10 (DBVDD), U6.32 (AVDD), Y1.1 (TRI-STATE), Y1.4 (VDD); also elsewhere on the board
DAC: R17.2, U6.14 (DACAT)
GND: C12.2, C13.2, C14.2, C15.2, C16.2, C18.1, C26.1, J2.1 (SLEEVE), R23.2, U6.9 (DGND), U6.20 (SPKGND2), U6.24 (SPKGND1), U6.28 (AGND), U6.33 (GNDPAD), Y1.2 (GND); also elsewhere on the board
GPIO14_HP_DETECT: J2.4 (RING2), J2.5 (TIP_SWITCH), R23.1; also elsewhere on the board
GPIO_18_BCLK: R16.1; also elsewhere on the board
GPIO_19_LRCLK: R18.1; also elsewhere on the board
GPIO_20_I2S_ADC: R19.1; also elsewhere on the board
GPIO_21_SD: R17.1; also elsewhere on the board
HP_L: C35.2, J2.3 (RING1)
HP_R: C36.2, J2.2 (TIP)
I2S_MCLK: R15.1, Y1.3 (OUTPUT)
MCLK: R15.2, U6.11 (MCLK)
unnamed: C14.1, U6.27 (VMID)
unnamed: C35.1, U6.31 (HP_L)
unnamed: C36.1, U6.29 (HP_R)
SCL1: U6.17 (SCL); also elsewhere on the board
SDA1: U6.18 (SDA); also elsewhere on the board
SPK_LN: L-.TP, U6.23 (SPK_LN)
SPK_LP: L+.TP, U6.25 (SPK_LP)
SPK_RN: R-.TP, U6.19 (SPK_RN)
SPK_RP: R+.TP, U6.22 (SPK_RP)
WS: R18.2, U6.13 (DACLRC), U6.15 (ADCLRC/GPIO1)

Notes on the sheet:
WM8960
24MHz
0.1uF

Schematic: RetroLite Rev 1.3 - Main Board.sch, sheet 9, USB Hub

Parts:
C40: 1uF; C0603
C45, C48: 18pF; C0603
R25: 12k; 0603
R27, R28, R29, R40: 56k; 0603
U9: USB2422T/MJ; SQFN24_4X4MC_MCH
U10, U12, U13: RCLAMP0582BQTCT; SC75-3L_SEM
Y2: ECS-240-8-36CKM-TR; XTAL_ECS-160-10-36-JGN-TR

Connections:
3V3: U9.1 (VDD33), U9.9 (VDD33), U9.15 (RESET_N), U9.16 (VBUS_DET), U9.18 (VDD33); also elsewhere on the board
D1_PORT_N: U9.4 (USBDN_DN2), U10.2; also elsewhere on the board
D1_PORT_P: U9.5 (USBDP_DN2), U10.1; also elsewhere on the board
D_N: U9.2 (USBDN_DN1), U12.2; also elsewhere on the board
D_P: U9.3 (USBDP_DN1), U12.1; also elsewhere on the board
GND: C40.1, C45.2, C48.2, R25.2, R27.2, R28.2, R40.2, U9.25 (GND), U10.3, U12.3, U13.3, Y2.2 (GND), Y2.4 (GND); also elsewhere on the board
unnamed: R40.1, U9.14 (SMBCLK/CFG_SEL)
unnamed: R25.1, U9.24 (RBIAS)
unnamed: C40.2, U9.10 (CFRILT)
unnamed: R28.1, U9.17 (SUSP_IND/NON_REM0)
unnamed: R27.1, U9.13 (SMBDAT/NON_REM1)
unnamed: C45.1, R29.1, U9.21 (XTALOUT), Y2.1 (IN/OUT)
unnamed: C48.1, R29.2, U9.22 (XTALIN_CLKIN), Y2.3 (OUT/IN)
USB_PI_N: U9.19 (USBDN_UP), U13.2; also elsewhere on the board
USB_PI_P: U9.20 (USBDP_UP), U13.1; also elsewhere on the board

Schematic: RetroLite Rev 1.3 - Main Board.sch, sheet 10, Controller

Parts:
C37: 0.1uF; R0402
LEFTPCB: 1-1734839-4; TE_1-1734839-4
R24: 100K; R0402
RIGHTPCB: 1-1734839-4; TE_1-1734839-4
U4: TS3USB221A; QFN-10-RSE

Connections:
3V3: C37.2, U4.10 (VCC); also elsewhere on the board
+5V: LEFTPCB.1, RIGHTPCB.14; also elsewhere on the board
A2: LEFTPCB.5, RIGHTPCB.10
A3: LEFTPCB.6, RIGHTPCB.9
D1_PORT_N: U4.4 (2D-); also elsewhere on the board
D1_PORT_P: U4.3 (2D+); also elsewhere on the board
D8: LEFTPCB.7, RIGHTPCB.8
D9: LEFTPCB.8, RIGHTPCB.7
D10: LEFTPCB.9, RIGHTPCB.6
D11: LEFTPCB.10, RIGHTPCB.5
D12: LEFTPCB.11, RIGHTPCB.4
D13: LEFTPCB.12, RIGHTPCB.3
D15: LEFTPCB.13, RIGHTPCB.2
D16: LEFTPCB.14, RIGHTPCB.1
D_N: RIGHTPCB.13, U4.2 (1D-); also elsewhere on the board
D_P: RIGHTPCB.12, U4.1 (1D+); also elsewhere on the board
GND: C37.1, LEFTPCB.4, LEFTPCB.P1 (S), LEFTPCB.P2 (S), R24.2, RIGHTPCB.11, RIGHTPCB.P1 (S), RIGHTPCB.P2 (S), U4.5 (VSS), U4.6 (!OE); also elsewhere on the board
SBU1_DOCK: R24.1, U4.9 (S); also elsewhere on the board
USB_PI_N: U4.7 (D-); also elsewhere on the board
USB_PI_P: U4.8 (D+); also elsewhere on the board

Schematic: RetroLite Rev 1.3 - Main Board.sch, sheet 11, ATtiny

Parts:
C17, C19, C62: 0.1uF; C0603
J6: 0781710004; MOLEX_0781710004
JU_2, JU_3, JU_5: 0; R0402
R5, R32, R33: 4.7k; R0603
R31, R34, R56: 10k; R0603
R54: 1k; R0603
R55: 15k; R0603
U14: MCU-ATTINY84A-MU(QFN20); QFN20G-0.5-4X4MM
U19, U20: SN74LVC1G17DCKR; SOT65P210X110-5N
U$29: 1MM_PIC_PROGRAMING_HEADER; 1MM_PIC-PROGRAMING_HEADER

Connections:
+5V: R34.1; also elsewhere on the board
BMS_SDA/MOSI: R32.2, U14.16 (PA6(ADC6/DI/MOSI/SDA/OC1A/PCINT6)), U$29.4; also elsewhere on the board
BMS_STAT: R34.2, R54.1; also elsewhere on the board
CM4_3.3V(OUTPUT): C17.1, R56.2, U20.5 (VCC); also elsewhere on the board
EN: R31.2, U14.4 (PA1(ADC1/AIN0/PCINT1)); also elsewhere on the board
GLOBAL_EN: JU_2.1, JU_2.2, U14.15 (PA7(ADC7/OC0B/ICP/PCINT7)); also elsewhere on the board
GND: C17.2, C19.1, C62.1, J6.4, J6.S1 (SHIELD), J6.S2 (SHIELD), R31.1, R55.2, R56.1, U14.8 (GND), U14.PAD, U19.3 (GND), U20.3 (GND), U$29.2; also elsewhere on the board
GPIO4_BMS_STAT: R54.2, R55.1; also elsewhere on the board
GPIO15_V-: J6.3; also elsewhere on the board
GPIO16_VOLTAGE_SHUTDOWN: U19.2 (A); also elsewhere on the board
GPIO16_VOLTAGE_SHUTDOWN_ATTINY: U14.5 (PA0(ADC0/AREF/PCINT0)), U19.4 (Y)
GPIO24_V+: J6.2; also elsewhere on the board
GPIO25_PI_SHUTDOWN_INIT: JU_5.2; also elsewhere on the board
GPIO25_PI_SHUTDOWN_INIT_ATTINY: U14.3 (PA2(ADC2/AIN1/PCINT2)), U20.2 (A)
GPIO25_PI_SHUTDOWN_INIT_JUP: JU_5.1, U20.4 (Y)
MISO: U14.20 (PA5(ADC5/DO/MISO/OC1B/PCINT5), U$29.5
PWR_BUTTON: J6.1, U14.14 (PB2(PCINT10/INT0/OC0A/CLKOUT))
RESET: R5.2, U14.13 (PB3(PCINT11/DW/!RESET)), U$29.6
RUN_PG: JU_3.1, JU_3.2, U14.2 (PA3(ADC3/T0/PCINT3)); also elsewhere on the board
SCK/BMS_SCL: R33.2, U14.1 (PA4(ADC4/USCK/SCL/T1/PCINT4)), U$29.3; also elsewhere on the board
VSYS: C19.2, C62.2, R5.1, R32.1, R33.1, U14.9 (VCC), U19.5 (VCC), U$29.1; also elsewhere on the board

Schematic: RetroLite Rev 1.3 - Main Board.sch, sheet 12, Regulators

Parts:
C32, C63: 1uF; 0603-NO
C41, C42, C43, C44, C47: 1.0uF; 0603
C46: 10uF; 0805
R26: 510K; R0603
R35: 162K; R0603
U8: TPS61230DRCT; SON50P300X300X100-11N
U16: TPS82085; SON65P280X300X133-9N
U18: INDUCTOR_SMALL

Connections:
3V3: C32.1, C47.2, C63.1, R26.2, U16.8 (VOUT); also elsewhere on the board
+5V: C41.1, C42.1, C43.1, U8.3 (VOUT), U8.4 (COUT), U8.7 (FB); also elsewhere on the board
CM4_3.3V(OUTPUT): U16.1 (EN); also elsewhere on the board
EN: U8.9 (EN); also elsewhere on the board
GND: C32.2, C41.2, C42.2, C43.2, C44.1, C46.1, C47.1, C63.2, R35.1, U8.11 (GND), U16.5 (GND), U16.6 (GND), U16.9 (GND), U16.P$1 (GND), U16.P$2 (GND), U16.P$3 (GND); also elsewhere on the board
unnamed: U8.1 (SW_1), U8.2 (SW_2), U18.1
unnamed: R26.1, R35.2, U16.7 (FB)
VSYS: C44.2, C46.2, U8.10 (VIN), U16.3 (VIN), U16.4 (VIN), U18.2; also elsewhere on the board

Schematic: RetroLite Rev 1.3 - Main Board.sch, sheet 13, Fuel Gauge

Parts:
C64: 0.47uF; C0402
C65: 0.1uF; C0402
R38, R47, R53: 4.7k; R0603
R39: PS0306DRF7T0R01L
U11: MAX17055ETB+T; 21-100013A_T102A2+1C_MXM

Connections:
BAT: C65.1, U11.10 (BATT); also elsewhere on the board
CM4_3.3V(OUTPUT): R38.1, R47.1, R53.1; also elsewhere on the board
GND: R39.1; also elsewhere on the board
GPIO17_INT: R53.2, U11.8 (ALRT); also elsewhere on the board
unnamed: C64.1, U11.7 (REG)
unnamed: R39.2, U11.5 (CSN)
unnamed: R39.3, U11.2 (AIN), U11.6 (CSP), U11.11 (EPAD)
PK-: C64.2, C65.2, R39.4; also elsewhere on the board
SCL1: R47.2, U11.3 (SCL); also elsewhere on the board
SDA1: R38.2, U11.4 (SDA); also elsewhere on the board

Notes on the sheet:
R39
0.01Ω

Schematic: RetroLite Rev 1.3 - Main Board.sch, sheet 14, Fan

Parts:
D1: BAS70; SOT23
J3: 2026560021; CONN_2026560021_MOL
Q1: AO3400A; SOT95P280X125-3N
R52: 10k; R0603

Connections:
+5V: D1.3 (C), J3.1; also elsewhere on the board
GND: Q1.2 (S), R52.1; also elsewhere on the board
GPIO13_PI_FAN: Q1.1 (G), R52.2; also elsewhere on the board
unnamed: D1.1 (A), J3.2, Q1.3 (D)



Board: 4 copper layers, 79.5 x 86.0 mm, 202 parts (201 on the bottom side), 200 nets.

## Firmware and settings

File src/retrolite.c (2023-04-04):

//Compile with: gcc retrolite.c -o retrolite -lwiringPi
#define _GNU_SOURCE
#define _POSIX_C_SOURCE 200809 L

//#include <iostream>
#include <inttypes.h>
#include <assert.h>
#include <stdbool.h>
#include <stdio.h>
#include <limits.h>
#include <stdlib.h>
#include <unistd.h>
#include <time.h>
#include <strings.h>
#include "font.h"
#include "imageGraphics.h"
#include "imageLayer.h"
#include "loadpng.h"
#include <unistd.h>
#include <math.h>
#include <SDL.h>
#include <fcntl.h>
#include "bcm_host.h"
#include <wiringPiI2C.h> //sudo apt-get install wiringpi
#include <wiringPi.h>
#include <wiringSerial.h>
#include <softPwm.h>
#include "retrolite.h"
#include "display.h"
#include "max17055.h"

int main() {
  //Local Variables
  int time;

  //Display Setup
  displaySetup();

  //GPIO Setup
  wiringPiSetup();

  pinMode(volUp_button, INPUT);
  pullUpDnControl(volUp_button, PUD_UP);
  pinMode(volDn_button, INPUT);
  pullUpDnControl(volDn_button, PUD_UP);
  pinMode(hpd_detect, INPUT);
  pullUpDnControl(hpd_detect, PUD_UP);
  pinMode(pwr_button, INPUT);
  pinMode(charge_detect, INPUT);
  pinMode(pwm_Brightness, PWM_OUTPUT);
  pinMode(fan_pwm, PWM_OUTPUT);
  pinMode(low_voltage_shutdown, OUTPUT);
  pwmSetMode(PWM_MODE_MS);
  pwmSetRange(101);
  pwmSetClock(10);
  pwmWrite(pwm_Brightness, brightness); //Set brightness to full
  pwmWrite(fan_pwm, fanSpeed); //Set fan speed to default (off)
  digitalWrite(low_voltage_shutdown, LOW);

  //Load Config Values
  loadValues();

  //Max17055 Fuel Gauge Setup
  I2CDevice = wiringPiI2CSetup(I2CAddress);
  max17055_Status = wiringPiI2CReadReg16(I2CDevice, 0x00);
  if (max17055_Status == -1) {
    printf("Max17055 Failed to Connect, Battery information unavailable.\n");
  } else {
    printf("Max17055 Connected.\n");
    max17055Init();
  }

  // Serial Port
  if ((controllerSerial = serialOpen("/dev/ttyACM0", 19200)) < 0) {
    printf("Failed to open Serial Port /dev/ttyACM0\n");
  } else {
    serialFlush(controllerSerial); // Flush all missed inputs
  }

  while (run) {

    time = millis();

    //Battery
    if (charging == false) {
      updateBatteryImage();
    } else {
      batteryChargingDisplay();
    }
    if (batteryLevelChanged) {
      if (batteryIconLayerEN) {
        destroyImageLayer( & batteryIconLayer);
      }
      displayImage(level_Icon, displayX - statusIconSize - 1, 1, & batteryIconLayer, 1);
      batteryIconLayerEN = true;
      batteryLevelChanged = false;
    }
    updateBatteryText();

    //Calibration Overlay
    if (calibrationStep != 0) {
      if (calibrationStep == 1) {
        strncpy(overlayImage, "./overlays/calibration1.png", 60);
      }
      if (calibrationStep == 2) {
        strncpy(overlayImage, "./overlays/calibration2.png", 60);
      }
      if (calibrationStep == 3) {
        strncpy(overlayImage, "./overlays/calibration3.png", 60);
      }
      if (calibrationStepChanged) {
        if (menuLayerEN) {
          destroyImageLayer( & menuLayer);
        }
        menuLayerEN = true;
        displayImage(overlayImage, (displayX / 2) - (overlayImageX / 2), (displayY / 2) - (overlayImageY / 2), & menuLayer, 1);
        calibrationStepChanged = false;
      }
    }

    if (calibrationStep == 3 && calibrationTimerStarted == false) {
      endCalibrationTimer = time;
      calibrationTimerStarted = true;
    }
    if (endCalibrationTimer + 3000 < time && calibrationTimerStarted == true) {
      calibrationStep = 0;
      if (menuLayerEN) {
        destroyImageLayer( & menuLayer);
        menuLayerEN = false;
      }
      calibrationTimerStarted = false;
      //menuEnabled = true;
      menuActive = 0;
      menuUpdated = true;
    }

    //Volume/brightness bar display
    if (volBrightPressed) {
      if (strcmp(last_bar_Icon, bar_Icon) != 0) {
        if (volBrightLayerEN) {
          destroyImageLayer( & volBrightLayer);
        }
        volBrightLayerEN = true;
        displayImage(bar_Icon, 1, 1, & volBrightLayer, 1);
        strncpy(last_bar_Icon, bar_Icon, 60);
      } else {
        if (!volBrightLayerEN) {
          volBrightLayerEN = true;
          displayImage(bar_Icon, 1, 1, & volBrightLayer, 1);
          strncpy(last_bar_Icon, bar_Icon, 60);
        }
      }
      volBrightPressed = false;
    }
    if (iconTimer + 3000 < time) {
      if (volBrightLayerEN) {
        destroyImageLayer( & volBrightLayer);
        volBrightLayerEN = false;
      }
      iconTimer = 0;
    }

    //Low Battery Shut Down
    if (max17055_Status != -1) {
      if (!shutdownTimerStarted) {
        if (getSOC() == 0 && !charging) {
          strncpy(overlayImage, "./overlays/lowbatterywarning.png", 60);
          if (kbdLayerEN) {
            destroyImageLayer( & kbdLayer);
          }
          kbdLayerEN = true;
          displayImage(overlayImage, (displayX / 2) - (overlayImageX / 2), (displayY / 2) - (overlayImageY / 2), & kbdLayer, 1);
          calibrationStepChanged = false;
          shutdownTimer = time;
          shutdownTimerStarted = true;
        }
      } else {
        if (!charging) {
          if (shutdownTimer + 30000 < time) {
            printf("GPIO %d Set high", low_voltage_shutdown);
            digitalWrite(low_voltage_shutdown, HIGH); //Tells the Attiny to initiate shutdown.
          }
        } else {
          if (kbdLayerEN) {
            destroyImageLayer( & kbdLayer);
            shutdownTimerStarted = false;
            kbdLayerEN = false;
          }
        }
      }
    }

    //GPIO for Volume and Power
    if (GPIOTimer + 150 < time) {
      checkGPIO();
      GPIOTimer = time;
    }

    //Controller Serial Interface
    if (controllerSerial != -1) {
      controllerInterface();
    }

    //Set screen brightness
    pwmWrite(pwm_Brightness, map(brightness, 1, 100, 100, 1));

    //Fan Control
    fanControl();

    //Menu
    if (menuEnabled) {
      if (menuUpdated) {
        if (menuDisplayed != menuActive) {
          if (menuLayerEN) {
            destroyImageLayer( & menuLayer);
            menuLayerEN = false;
          }
          if (menuTextLayerEN) {
            destroyImageLayer( & menuTextLayer);
            menuTextLayerEN = false;
          }
          if (menuPointerLayerEN) {
            destroyImageLayer( & menuPointerLayer);
            menuPointerLayerEN = false;
          }
        } else {
          if (menuPointerLayerEN) {
            destroyImageLayer( & menuPointerLayer);
            menuPointerLayerEN = false;
          }
        }
        if (menuActive == 0) {
          mainMenu();
        } else if (menuActive == 1) {
          batteryMenu();
        } else if (menuActive == 2) {
          menuDisplayed = 2;
        } else if (menuActive == 3) {
          osKeyboard = true;
        } else if (menuActive == 4) {
          settingsMenu();
        }
        menuUpdated = false;
      }
    } else {
      if (menuLayerEN) {
        destroyImageLayer( & menuLayer);
        menuLayerEN = false;
      }
      if (menuTextLayerEN) {
        destroyImageLayer( & menuTextLayer);
        menuTextLayerEN = false;
      }
      if (menuPointerLayerEN) {
        destroyImageLayer( & menuPointerLayer);
        menuPointerLayerEN = false;
      }
    }

    //On Screen Keyboard
    if (osKeyboard) {
      //Display Keyboard
      if (keyCase == 1) {
        strncpy(overlayImage, "./keyboard/upperCase.png", 60);
      } else {
        strncpy(overlayImage, "./keyboard/lowerCase.png", 60);
      }
      if (lastKeyCase != keyCase || !kbdLayerEN) {
        if (kbdLayerEN) {
          destroyImageLayer( & kbdLayer);
        }
        kbdLayerEN = true;
        lastKeyCase = keyCase;
        displayImage(overlayImage, (displayX / 2) - (overlayImageX / 2), (displayY / 2) - (overlayImageY / 2), & kbdLayer, 1);
      }
      if (keyboardChanged) {
        //Update highlighted key
        char tempSTR[60];
        sprintf(tempSTR, "./keyboard/%d%d.png", keyboardRow, keyboardCollumn);
        strncpy(keyboardHighlight, tempSTR, 60);

        if (kbdHighlightLayerEN) {
          destroyImageLayer( & kbdHighlightLayer);
        }
        kbdHighlightLayerEN = true;
        displayImage(keyboardHighlight, (displayX / 2) - (overlayImageX / 2), (displayY / 2) - (overlayImageY / 2), & kbdHighlightLayer, 1);
        keyboardChanged = false;
      }
    } else {
      if (!shutdownTimerStarted) {
        if (kbdLayerEN) {
          destroyImageLayer( & kbdLayer);
          kbdLayerEN = false;
        }
        if (kbdHighlightLayerEN) {
          destroyImageLayer( & kbdHighlightLayer);
          kbdHighlightLayerEN = false;
        }
      }
    }

    //Print Ram Usage
    //char buf[BUFSIZ];
    //snprintf(buf, sizeof(buf), "free -h");
    //system(buf);

  }

  result = vc_dispmanx_display_close(display);
  assert(result == 0);

  //---------------------------------------------------------------------
  return 0;
}

long map(long x, long in_min, long in_max, long out_min, long out_max) {
  return (x - in_min) * (out_max - out_min) / (in_max - in_min) + out_min;
}

void checkResolution() {
  FILE * resolution;
  char path[35];
  int x = 0;
  int y = 0;
  char * token;

  resolution = popen("fbset -s", "r");

  fgets(path, sizeof(path), resolution); //Read first line
  fgets(path, sizeof(path), resolution); //Read second line
  fgets(path, sizeof(path), resolution); //Read third line

  token = strtok(path, " ");
  while (token != NULL) {
    if (atoi(token) != 0) {
      if (x == 0) {
        x = atoi(token);
      } else {
        if (y == 0) {
          y = atoi(token);
        }
      }

    }
    token = strtok(NULL, " ");
  }
  printf("X Resolution = %d\n", x);
  printf("Y Resolution = %d\n", y);

  displayX = x;
  displayY = y;

  pclose(resolution);
}

void controllerInterface() {
  int value;

  while (serialDataAvail(controllerSerial)) {
    value = serialGetchar(controllerSerial);
    if (value == brightnessUp) {
      if (brightness <= 90) {
        brightness += 10;
        saveValues();
      }

      iconTimer = millis();
      volBrightPressed = true;
    }
    if (value == brightnessDn) {
      if (brightness >= 10) {
        brightness -= 10;
        saveValues();
      }
      iconTimer = millis();
      volBrightPressed = true;
    }
    if (value == menuOpen) {
      menuEnabled = true;
      menuUpdated = true;
      menuSelected = 1;
      printf("Menu Enabled\n");
    }
    if (value == menuClose) {
      menuEnabled = false;
      osKeyboard = false;
      menuActive = 0;
      printf("Menu Disabled\n");
    }
    if (!osKeyboard && menuActive != 1) {
      if (value == osKeyboardUp) {
        //Menu Selection Up
        if (menuSelected > 1 && menuSelected != 7) {
          menuSelected -= 1;
          menuUpdated = true;
        } else if (menuSelected == 7) {
          menuSelected = 5;
          menuUpdated = true;
        }
      }
      if (value == osKeyboardDn) {
        //Menu Selection Down
        if (menuActive != 4) {
          if (menuSelected < 4) {
            menuSelected += 1;
            menuUpdated = true;
          }
        } else {
          if (menuSelected < 5) {
            menuSelected += 1;
            menuUpdated = true;
          } else if (menuSelected == 5) {
            menuSelected = 7;
            menuUpdated = true;
          }
        }
      }
    }
    if (value == osKeyboardLeft) {
      if (menuActive == 4) {
        settingValueChanged(-1);
      }
    }
    if (value == osKeyboardRight) {
      if (menuActive == 4) {
        settingValueChanged(1);
      }
    }
    if (value == osKeyboardSelect) {
      if (calibrationStep == 0) {
        menuOptionSelected();
      }
    }
    /*if(value == calibrationStepOne){
        printf("Calibration Step 1\n");
        calibrationStep = 1;
        calibrationStepChanged = true;
    }*/
    if (value == calibrationStepTwo) {
      printf("Calibration Step 2\n");
      calibrationStep = 2;
      calibrationStepChanged = true;
    }
    if (value == calibrationComplete) {
      printf("Calibration Step 3\n");
      calibrationStep = 3;
      calibrationStepChanged = true;
    }
    //On Screen Keyboard
    if (value == osKeyboardEnabled) {
      osKeyboard = true;
      keyboardChanged = true;
    }
    if (value == osKeyboardDisabled) {
      osKeyboard = false;
      if (kbdHighlightLayerEN) {
        destroyImageLayer( & kbdHighlightLayer);
        kbdHighlightLayerEN = false;
      }
      if (kbdLayerEN) {
        destroyImageLayer( & kbdLayer);
        kbdLayerEN = false;
      }
    }
    if (osKeyboard) {
      if (value == osKeyboardLeft) {
        if (keyboardCollumn > 0) {
          keyboardCollumn--;
        } else {
          if (keyboardRow != 0) {
            keyboardCollumn = 9;
          } else {
            keyboardCollumn = 6;
          }
        }
        keyboardChanged = true;
      }
      if (value == osKeyboardRight) {
        if (keyboardRow != 0) {
          if (keyboardCollumn < 9) {
            keyboardCollumn++;
          } else {
            keyboardCollumn = 0;
          }
        } else {
          if (keyboardCollumn < 6) {
            keyboardCollumn++;
          } else {
            keyboardCollumn = 0;
          }
        }
        keyboardChanged = true;
      }
      if (value == osKeyboardUp) {
        if (keyboardRow == 0) {
          if (keyboardCollumn == 3) {
            keyboardCollumn = 4;
          } else if (keyboardCollumn == 4) {
            keyboardCollumn = 6;
          } else if (keyboardCollumn == 5) {
            keyboardCollumn = 7;
          } else if (keyboardCollumn > 5) {
            keyboardCollumn = 9;
          }
        }
        if (keyboardRow < 4) {
          keyboardRow++;
        } else {
          keyboardRow = 0;
        }
        if (keyboardRow == 0) {
          if (keyboardCollumn == 6) {
            keyboardCollumn = 4;
          } else if (keyboardCollumn == 7) {
            keyboardCollumn = 5;
          } else if (keyboardCollumn > 7) {
            keyboardCollumn = 6;
          } else if (keyboardCollumn == 3 || keyboardCollumn == 4 || keyboardCollumn == 5) {
            keyboardCollumn = 3;
          }
        }
        keyboardChanged = true;
      }
      if (value == osKeyboardDn) {
        if (keyboardRow == 0) {
          if (keyboardCollumn == 4) {
            keyboardCollumn = 6;
          } else if (keyboardCollumn == 5) {
            keyboardCollumn = 7;
          } else if (keyboardCollumn == 6) {
            keyboardCollumn = 9;
          } else if (keyboardCollumn == 3) {
            keyboardCollumn = 4;
          }
        }
        if (keyboardRow > 0) {
          keyboardRow--;
        } else {
          keyboardRow = 4;
        }
        if (keyboardRow == 0) {
          if (keyboardCollumn == 6) {
            keyboardCollumn = 4;
          } else if (keyboardCollumn == 7) {
            keyboardCollumn = 5;
          } else if (keyboardCollumn > 7) {
            keyboardCollumn = 6;
          } else if (keyboardCollumn == 3 || keyboardCollumn == 4 || keyboardCollumn == 5) {
            keyboardCollumn = 3;
          }
        }
        keyboardChanged = true;
      }
      if (value == osKeyboardSelect) {
        if (keyboardRow == 1 && keyboardCollumn == 0) { //Caps Lock
          if (keyCase == 0) {
            keyCase = 1;
          } else {
            keyCase = 0;
          }
        } else {
          if (keyCase == 0) { //Lower Case
            serialPrintf(controllerSerial, "%c", osKeyboardLowercase[keyboardRow][keyboardCollumn]);
          } else { //Upper Case
            serialPrintf(controllerSerial, "%c", osKeyboardUppercase[keyboardRow][keyboardCollumn]);
          }
        }
        keyboardChanged = true;
      }
    }

    if (volBrightPressed) {
      if (brightness == 0) {
        strncpy(bar_Icon, "./brightnessIcons/brightness_0.png", 60);
      } else if (brightness == 10) {
        strncpy(bar_Icon, "./brightnessIcons/brightness_10.png", 60);
      } else if (brightness == 20) {
        strncpy(bar_Icon, "./brightnessIcons/brightness_20.png", 60);
      } else if (brightness == 30) {
        strncpy(bar_Icon, "./brightnessIcons/brightness_30.png", 60);
      } else if (brightness == 40) {
        strncpy(bar_Icon, "./brightnessIcons/brightness_40.png", 60);
      } else if (brightness == 50) {
        strncpy(bar_Icon, "./brightnessIcons/brightness_50.png", 60);
      } else if (brightness == 60) {
        strncpy(bar_Icon, "./brightnessIcons/brightness_60.png", 60);
      } else if (brightness == 70) {
        strncpy(bar_Icon, "./brightnessIcons/brightness_70.png", 60);
      } else if (brightness == 80) {
        strncpy(bar_Icon, "./brightnessIcons/brightness_80.png", 60);
      } else if (brightness == 90) {
        strncpy(bar_Icon, "./brightnessIcons/brightness_90.png", 60);
      } else if (brightness == 100) {
        strncpy(bar_Icon, "./brightnessIcons/brightness_100.png", 60);
      }
    }
  }
}

void loadValues() {
  FILE * fp;
  char buff[255];
  int parsingFailed = false;
  int temp;

  fp = fopen("config", "r");
  if (fp == NULL) {
    printf("Failed to load config file, using defaults\n");
    return;
  }
  fgets(buff, 255, (FILE * ) fp);
  sscanf(buff, "%d %f %d %d %d %d", & batteryCapacity, & lowVoltageThreshold, & cpuFanThreshold, & brightness, & volume, & darkMode);
  fclose(fp);

  //Input Parsing
  if (brightness > 100 || brightness < 1) {
    brightness = 1;
    parsingFailed = true;
  } else {
    temp = brightness / 10;
    brightness = temp * 10;
    parsingFailed = true;
  }
  if (volume > 100 || volume < 0) {
    volume = 100;
    parsingFailed = true;
  } else {
    temp = volume / 10;
    volume = temp * 10;
    parsingFailed = true;
  }
  if (lowVoltageThreshold < 2.8) {
    lowVoltageThreshold = 3.0;
    parsingFailed = true;
  }
  if (parsingFailed) {
    saveValues();
  }
  float test = getVEmpty();
  printf("batteryCapacity: %d\n", batteryCapacity);
  printf("lowVoltageThreshold: %f\n", lowVoltageThreshold);
  printf("cpuFanThreshold: %d\n", cpuFanThreshold);
  printf("brightness: %d\n", brightness);
  printf("volume: %d\n", volume);
  printf("DarkMode: %d\n", darkMode);
  printf("VEmpty: %.2f\n", test);
}

void saveValues() {
  FILE * fptr;
  fptr = fopen("config", "w");
  if (fptr == NULL) {
    printf("Error Logging Values! \n");
    return;
  } else {
    fprintf(fptr, "%d %.1f %d %d %d %d", batteryCapacity, lowVoltageThreshold, cpuFanThreshold, brightness, volume, darkMode);
  }
  fclose(fptr);
}

void updateBatteryImage() {
  char currentIcon[60];
  strncpy(currentIcon, level_Icon, 60);
  if (max17055_Status != -1) { //Check if Max17055 is connected
    currentSOC = getSOC();
    if (currentSOC > 90) {
      strncpy(level_Icon, "./batteryIcons/battery_full_white_18dp.png", 60);
    } else if (currentSOC > 80) {
      strncpy(level_Icon, "./batteryIcons/battery_90_white_18dp.png", 60);
    } else if (currentSOC > 70) {
      strncpy(level_Icon, "./batteryIcons/battery_80_white_18dp.png", 60);
    } else if (currentSOC > 60) {
      strncpy(level_Icon, "./batteryIcons/battery_70_white_18dp.png", 60);
    } else if (currentSOC > 50) {
      strncpy(level_Icon, "./batteryIcons/battery_60_white_18dp.png", 60);
    } else if (currentSOC > 40) {
      strncpy(level_Icon, "./batteryIcons/battery_50_white_18dp.png", 60);
    } else if (currentSOC > 30) {
      strncpy(level_Icon, "./batteryIcons/battery_40_white_18dp.png", 60);
    } else if (currentSOC > 20) {
      strncpy(level_Icon, "./batteryIcons/battery_30_white_18dp.png", 60);
    } else if (currentSOC > 10) {
      strncpy(level_Icon, "./batteryIcons/battery_20_white_18dp.png", 60);
    } else if (currentSOC > 0) {
      strncpy(level_Icon, "./batteryIcons/battery_10_white_18dp.png", 60);
    } else {
      strncpy(level_Icon, "./batteryIcons/battery_0_white_18dp.png", 60);
    }
  } else {
    strncpy(level_Icon, "./batteryIcons/battery_error_18d.png", 60);
  }
  if (strcmp(currentIcon, level_Icon) != 0) {
    //printf("Level Icon Changed\n");
    batteryLevelChanged = true;
  }
}

void batteryChargingDisplay() {
  unsigned int time = millis();
  if (chargeIconTimer + 1000 < time) {
    chargeIconTimer = time;
    batteryLevelChanged = true;
    if (chargeStep < 4) {
      chargeStep += 1;
    } else {
      chargeStep = 0;
    }
  }
  if (chargeStep == 0) {
    strncpy(level_Icon, "./batteryIcons/battery_charge_0_18dp.png", 60);
  } else if (chargeStep == 1) {
    strncpy(level_Icon, "./batteryIcons/battery_charge_1_18dp.png", 60);
  } else if (chargeStep == 2) {
    strncpy(level_Icon, "./batteryIcons/battery_charge_2_18dp.png", 60);
  } else if (chargeStep == 3) {
    strncpy(level_Icon, "./batteryIcons/battery_charge_3_18dp.png", 60);
  } else if (chargeStep == 4) {
    strncpy(level_Icon, "./batteryIcons/battery_charge_4_18dp.png", 60);
  }
}
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

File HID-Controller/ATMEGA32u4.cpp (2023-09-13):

/*  
 * ATMEGA32u4 USB Joypad for project Retrolite CM4.
 * Default configuration - 2 Joysticks, 13 Buttons, 1 Dpad.
 * 
 * Joystick calibration:
 * 1: Press the buttons on pins D0 and D3 simultaneously to put the controller into calibration mode.
 * 2: Centre both joysticks and press the button on pin D1 to record mid position, RX LED will blink once to confirm step complete.
 * 3: Move both joysticks to full extents of travel several times to record maximum axis values.
 * 4: Press button on D1 again. RX LED will blink once more to confirm.
 * 5: Calibration is now complete and stored.
 * 
 * If you're using this controller with Windows, you will also need to run the windows joypad calibration once you've completed the internal calibration.
 * If you change joysticks or your centerpoint drifts (thanks, nintendo) re-running the internal calibration should solve the problem.
 * 
 * Note: Whilst controller is in calibration mode all USB control output will cease until calibration is complete or controller is restarted.
 * 
 * Created by - Daniel McKenzie
 * 03-12-2021 v1.4
 */

#include <Joystick.h> //https://github.com/MHeironimus/ArduinoJoystickLibrary
#include "Keyboard.h"
#include "Mouse.h"
#include <EEPROM.h>

//Serial Comms
byte brightnessUp = 0x00;
byte brightnessDn = 0x01;
byte calibrationStepOne = 0x02;
byte calibrationStepTwo = 0x03;
byte calibrationComplete = 0x04;
byte osKeyboardEnabled = 0x05;
byte osKeyboardLeft = 0x06;
byte osKeyboardRight = 0x07;
byte osKeyboardUp = 0x08;
byte osKeyboardDn = 0x09;
byte osKeyboardSelect = 0x10;
byte osKeyboardDisabled = 0x11;
byte menuOpen = 0x12;
byte menuClose = 0x13;
byte povModeEnable = 0x14;
byte povModeDisable = 0x15;
byte mouseEnable = 0x16; //Currently unused. May be used in future to toggle mouse from OSD menu
byte mouseDisable = 0x17; //Currently unused. May be used in future to toggle mouse from OSD menu
int serialButtonDelay = 150;

//Options
const bool cycleTimeTest = false; //Enable to test CPU Cycle time.
#define baudrate 19200 //Baudrate for serial.

//Define button pins
byte buttonCount = 13; //Number of buttons in use. Change length of buttonPins, lastButtonState and currentButtonState to match.
byte buttonPins[13] = {0,1,2,3,4,5,6,7,12,13,14,15,16}; //Array to store digital pins used for buttons. Length must be the same as buttonCount.
byte dpadPins[4] = {8,11,9,10}; //Up, Right, Down, Left. Do not change order of directions.

//Button state arrays
byte dpadPinsState[4];  //Empty State array for dPad
byte lastButtonState[13]; //Empty State array for buttons last sent state. Must be same length as buttonPins
byte currentButtonState[13]; //Empty State array for buttons. Must be same length as buttonPins

//Define Analog Pins for joysticks
const int leftJoyX = A3;
const int leftJoyY = A2;
const int rightJoyX = A1;
const int rightJoyY = A0;

//Joystick Settings
const bool invertLeftY = false;   //------------------------------------------
const bool invertLeftX = false;    //Change these settings for Inverted mounting 
const bool invertRightY = true;  //of joysticks.
const bool invertRightX = true;  //------------------------------------------
const int deadBandLeft = 10;     //
const int deadBandRight = 10;    //Joystick deadband settings. Deadband is the same for both axis on each joystick.
const bool useDeadband = true;    //
const int earlyLeftX = 30;   //--------------------------------------------------
const int earlyLeftY = 30;   //Distance from end of travel to achieve full axis movement. 
const int earlyRightY = 30;  //This helps square out each axis response to allow full movement speed with direction input.
const int earlyRightX = 30;  //--------------------------------------------------
boolean scaledJoystickOutput = true; //Enable joystick scaling. Needed for switch joysticks due to uneven axis travels. Disabling will save some compute time if your joystick works well without it.

//Main Joystick setup
Joystick_ Joystick(JOYSTICK_DEFAULT_REPORT_ID,JOYSTICK_TYPE_GAMEPAD,
buttonCount, 1,       // Button Count, Hat Switch Count
true, true, true,     // X Y Z
true, true, true,  // Rx, Ry, Rz
false, false,          // Rudder, Throttle
false, false, false); // Accelerator, Brake, Steering

//Default Joystick calibration settings and EEPROM storage Address
int minLeftX = 330; //EEPROM Adr = 1
int maxLeftX = 830; //EEPROM Adr = 3
int midLeftX = 512; //EEPROM Adr = 5

int minLeftY = 205; //EEPROM Adr = 7
int maxLeftY = 635; //EEPROM Adr = 9
int midLeftY = 477; //EEPROM Adr = 11

int minRightY = 215; //EEPROM Adr = 13
int maxRightY = 730; //EEPROM Adr = 15
int midRightY = 529; //EEPROM Adr = 17

int minRightX = 300; //EEPROM Adr = 19
int maxRightX = 780; //EEPROM Adr = 21
int midRightX = 525; //EEPROM Adr = 23

//Joystick LookUp Tables, compiled at startup or after joystick calibration.
byte leftXLUT[350];
byte leftYLUT[350];
byte rightXLUT[350];
byte rightYLUT[350];

//All variables below general use, not used for configuration.
boolean calibrationMode = false;
int calibrationStep = 1;
long pollingTest;
float lastPollingMS;
long lastPollingReport;
unsigned long keyboardTimer;
boolean L3Pressed = false;
boolean menuEnabled = false;
boolean povHatMode = true; //Enable to use POV Hat for Dpad instead of analog

//Mouse Variables
boolean mouseEnabled = false;
int mouseDivider = 8; //Adjust this value to control mouse sensitivity. Higher number = slower response.
unsigned long mouseTimer;
int mouseInterval = 10; //Interval in MS between mouse updates
unsigned long mouseModeTimer;
boolean mouseModeTimerStarted = false;


void setup() {
  //Needed for Retropie to detect axis.
  Joystick.setXAxisRange(0, 254);
  Joystick.setYAxisRange(0, 254);
  Joystick.setZAxisRange(0, 254);
  Joystick.setRxAxisRange(0, 254);
  Joystick.setRyAxisRange(0, 2);
  Joystick.setRzAxisRange(0, 2);
  
  Serial.begin(baudrate);
  while (!Serial); //Needed on 32u4 based arduinos for predictable serial output.
  Joystick.begin(false); //Initialise joystick mode with auto sendState disabled as it has a huge processor time penalty for seemingly no benefit.
  Keyboard.begin(); //Initialise keyboard for on screen keyboard input
  Mouse.begin(); //Initialise mouse control
  
  for(int i = 0; i < buttonCount; i++){ //Set all button pins as input pullup. Change to INPUT if using external resistors.
    pinMode(buttonPins[i], INPUT_PULLUP);
  }
  for(int i = 0; i < 4; i++){ //Set all dpad button pins as input pullup.
    pinMode(dpadPins[i], INPUT_PULLUP);
  }
  
  eepromLoad(); //Check for stored joystick settings and load if applicable.
  rebuildLUTs(); //Build joystick LUT's from stored calibration values.
}
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

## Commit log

2021-12-26 Rename ATtiny84 Button Code.cpp to ATtiny84/RetroLiteMonitorScript
2021-12-27 Rename Retro Lite STLs/placeholder.txt to CAD Files/placeholder.txt
2022-05-18 Update fan code to follow linear ramp-up
    Added a temperature for zero speed and a temperature for full speed. When the temperature is between these two values, the the fan speed linearly increases with temperature. This allows the system to find the exact fan speed it needs to maintain equilibrium, and prevents any sharp bouncing
    [retrolite.c]
2022-09-06 Fix lowVoltageThreshold to work with OSD menu
    [max17055.h]
2022-09-06 Switch TTF with TTE on charge detect
2022-09-06 Fix SoC value when charger connect
    [retrolite.c]
2022-10-04 Add dock STLs
    [CM4 Dock Cover.stl, Retro Lite CM4 Dock.stl]
2022-10-04 Add dock STL files
    [Retro Lite CM4 Dock.stl]
2022-10-28 Add config.txt
    [config.txt]
2022-11-11 Retro Lite CM4 main housing .STEP files
    [Retro Lite CM4 Front v1.step, Retro Lite CM4 Rear v1.step, Trigger Mounts Left.step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]
2022-11-11 Create Housing
2022-11-11 Rename CAD Files/Retro Lite CM4 Front v1.step to CAD Files/Housing/Retro Lite CM4 Front v1.step
    [Retro Lite CM4 Front v1.step]
2022-11-11 Rename CAD Files/Trigger Mounts Left.step to CAD Files/Housing/Trigger Mounts Left.step
    [Trigger Mounts Left.step]
2022-11-11 Rename CAD Files/Trigger Mounts Right.step to CAD Files/Housing/Trigger Mounts Right.step
    [Trigger Mounts Right.step]
2022-11-11 Rename CAD Files/RetroLite Rev 1.3 - Main Board.brd to CAD Files/PCB/RetroLite Rev 1.3 - Main Board.brd
    [RetroLite Rev 1.3 - Main Board.brd]
2023-02-20 Add BatteryFullyCharged message to user
2023-02-20 Battery Menu Fix
    Fixed battery menu getting stuck on display when pressing up or down on the dpad whilst menu is open.
    [retrolite.c]
2023-02-20 Code Tidy
    Fixed Indentation and formatting errors to keep code style consistent
    [display.h]
2023-02-20 Headphone detect oscillation
    Fixed oscillation in the headphone detect code that was filling the terminal with text preventing usage of backend features of retropie
    [retrolite.c]
2023-02-22 Time to Full/Empty fix
    Added a leading zero to the minutes readout when values are under 10 to more accurately represent a "time"
    [display.h]
2023-03-27 Implement hysteresis & PID controller
2023-03-27 Update PID controller
2023-04-20 getControllerData()
    Created getControllerData function to handle controller serial comms. Checks serial connection before requesting data to avoid crashing. Returns controllerError when no data is available or the controller is disconnected.
    [retrolite.c]
2023-04-20 Fixed missing bracket
2023-09-13 Update ATMEGA32u4.cpp
    Joystick LUT overrun issue
    [ATMEGA32u4.cpp]

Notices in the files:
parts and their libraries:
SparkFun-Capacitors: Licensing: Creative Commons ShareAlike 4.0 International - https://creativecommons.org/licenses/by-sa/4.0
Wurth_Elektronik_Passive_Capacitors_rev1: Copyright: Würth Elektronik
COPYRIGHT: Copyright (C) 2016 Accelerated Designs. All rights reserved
